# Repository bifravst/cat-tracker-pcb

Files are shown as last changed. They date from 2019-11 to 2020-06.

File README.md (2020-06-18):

# Cat Tracker PCB (PCA10015)

Design files for a custom cat tracker board based on the [nRF9160](https://www.nordicsemi.com/Products/Low-power-cellular-IoT/nRF9160).

See [the PDF slides](./presentation.pdf) for an introduction to the design.

## Front

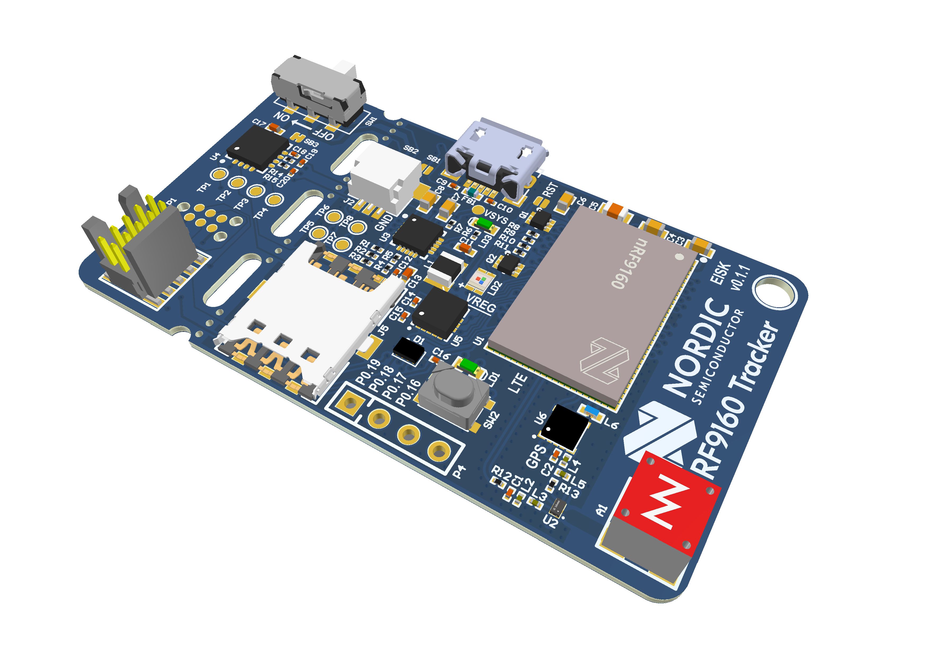
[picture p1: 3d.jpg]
3D Rendering


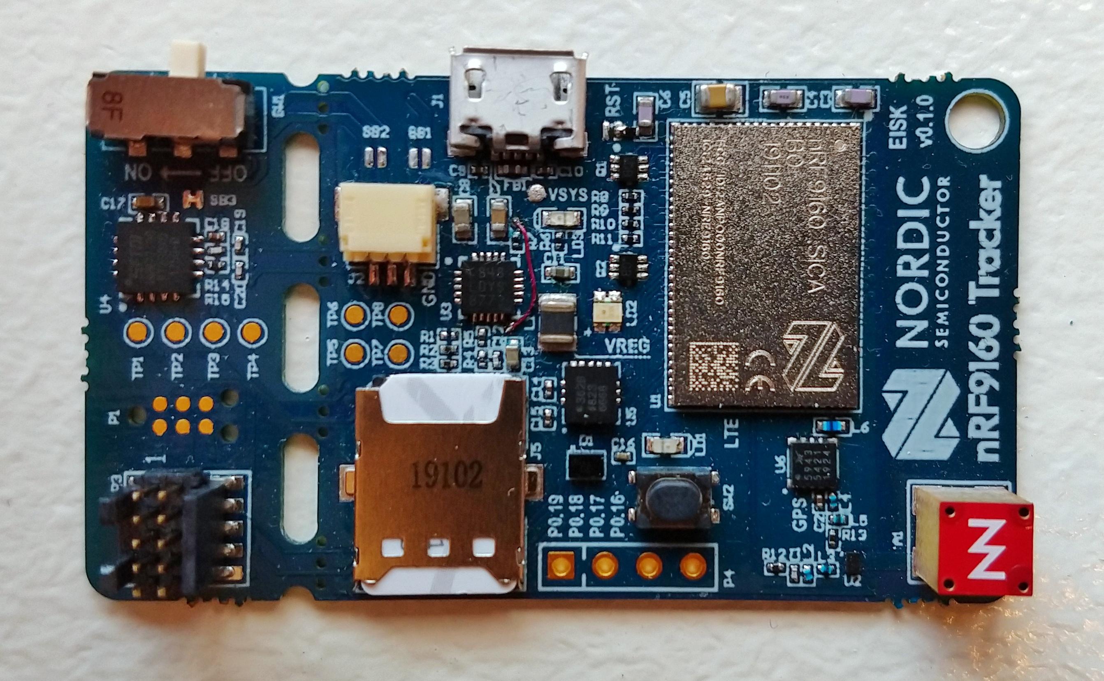
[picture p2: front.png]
Front


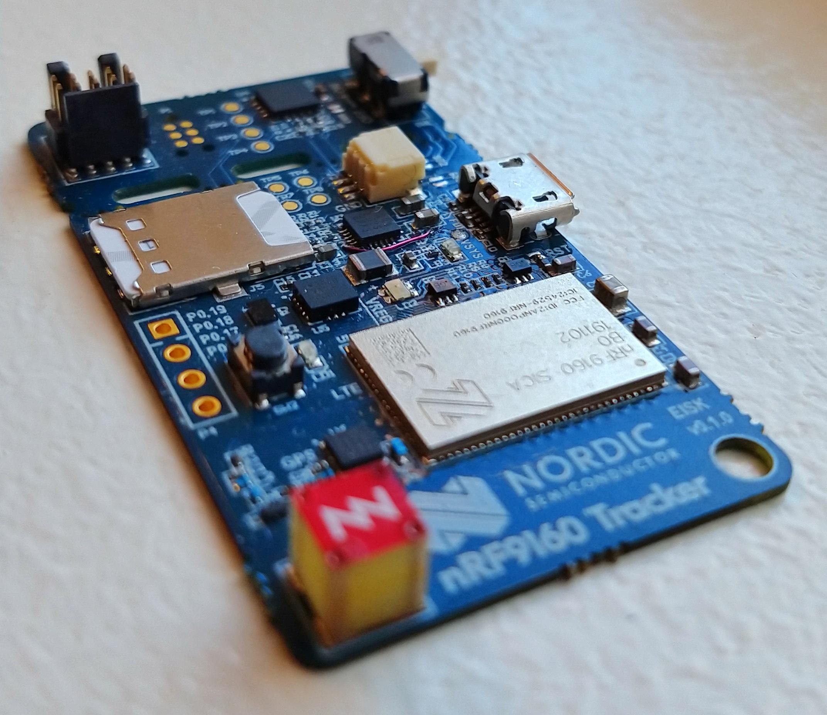
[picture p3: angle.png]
Front (angled view)


## Back

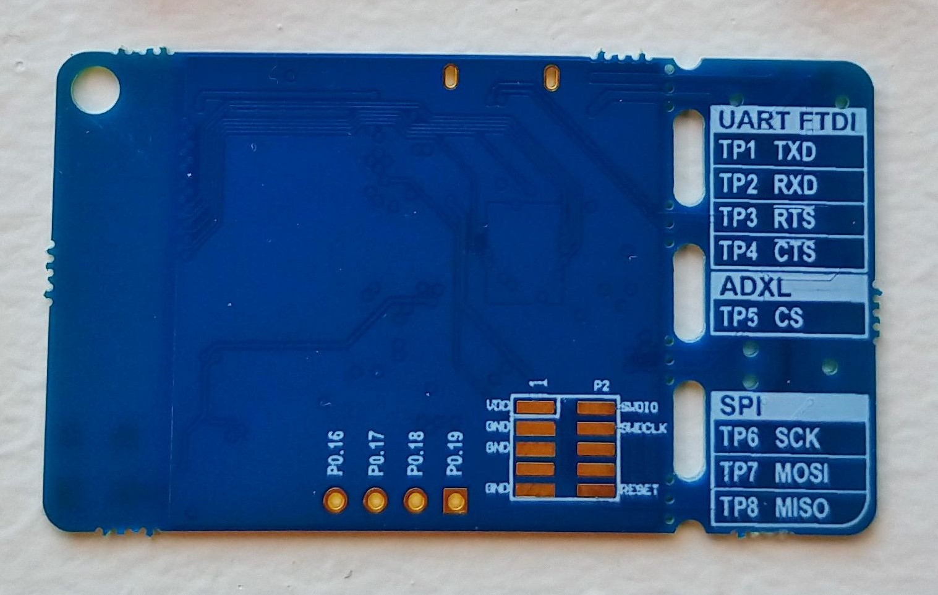
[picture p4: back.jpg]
Back


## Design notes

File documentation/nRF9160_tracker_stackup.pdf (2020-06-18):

nRF9160 Tracker Demo
v0.1.2

## 1 PCB Stackup

## 1.1 Stackup

Type | Material | Height [µm] Dk | Df
Mask | – | 15 | 3.5 | –
Prepreg | FR-4 | 70 | 4.2 | 0.02
Core | FR-4 | 500 | 4.5 | 0.02
Prepreg | FR-4 | 70 | 4.2 | 0.02
Mask | – | 15 | 3.5 | –
Type | Material | Height [µm] Weight [oz]
Finish | HASL-Pb Free 18 | 1/2
Cond | Cu | 18 | 1/2
Cond | Cu | 35 | 1

Top layer
Upper layer pair
Mid layer 1

(Vias are not shown)

Mid layer 2
Lower layer pair
Bottom layer

## 1.2 Layer Stack in Altium Designer 20

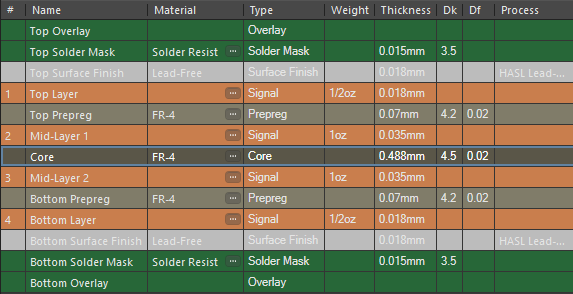
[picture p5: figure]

Figure 1: The Layer Stack of the PCB in Altium Designer 20.

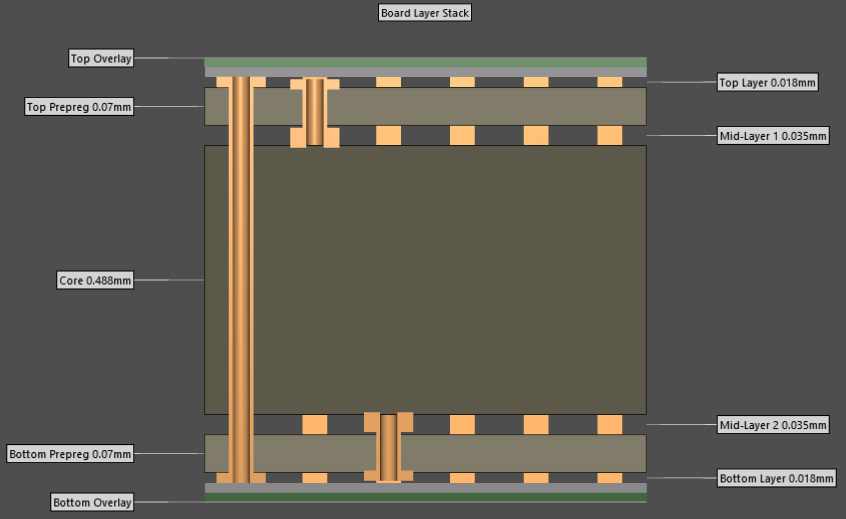
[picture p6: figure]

Figure 2: The Board Layer Stack, with real relative layer heights.

The total PCB thickness is approximately 0.8 mm.

## 1.3 Impedance Calculations

The transmission lines in the RF front end are grounded coplanar waveguides (GCPWs), which require a bottom ground plane in addition to coplanar ground planes. Simulations of the transmission lines are necessary to obtain a characteristic impedance of

Z0 = 50 Ω,

However, this is very challenging when embedding GCPWs on very small PCBs as the nRF9160 Tracker. It is important to have in mind that Z0 is dispersive and depends on the effective permittivity εeff, which satisfies

1 ≤ εeff ≤ εr

Only the upper layer pair is used in the nRF9160 Tracker, thus, the GCPWs for the LTE and the GPS circuitry only depend on the prepreg layer height and not the PCB core.

Altium Designer 20 can compute the characteristic impedance (in the Layer Stack Manager). It incorporates the solder mask layer and optionally, the surface finish layer in its calculation.

Free calculators like AppCAD Design Assistant (https://www.broadcom.com/appcad) or Saturn PCB Toolkit (http://saturnpcb.com/pcb_toolkit/) can also be used to calculate the characteristic line impedance Z0, as well as the effective permittivity εeff. However, values from these calculators do not take surface finish and solder mask into account, unlike Altium Designer 20. A comparison of calculated transmission line values on the nRF9160 Tracker is presented in table 1, when the clearance, the dielectric thickness and the relative permittivity, respectively are:

S = 200 μm,
t = 70 μm,
εr = 4.2.

Table 1: Comparison of calculated transmission line values in Altium and AppCAD.

| | Altium | AppCAD
Impedance | Z0
| [Ω] | 50.0 | 51.0
Delay | Tp
| [ns/m] | 6.08 | 5.46
Line Width | W [μm] | 102 | 150

The AppCAD line width value of W = 150 μm is used in nRF9160 Tracker v0.1.2.

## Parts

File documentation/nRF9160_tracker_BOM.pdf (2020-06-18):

Item # | Designator | Description | Name | Quantity | Manufacturer 1 | Manufacturer Part Number 1 | Footprint | LibRef | Note
1 | A1 | CUBE mXTEND Antenna Booster (GSM, UMTS, LTE) | FR01-S4-250 | 1 | Fractus | FR01-S4-250 | FRACTUS_CUBE_mXTEND | ANT:CUBE_mXTEND
2 | C1 | Capacitor, NP0, ±10%, 10V | 3pF | 1 | Murata | GJM0335C1E3R0WB01D | CAPC0603X03L_C
3 | C2, C9, C14, C15, C18 | Capacitor, X5R, ±10%, 10V | 100nF | 5 | | | CAPC0603X03L_C
4 | C3, C4, C6 | Capacitor, X5R, ±10%, 6.3V | 4.7µF | 3 | | | CAPC1608X06L
5 | C5 | Capacitor, X5R, ±20%, 6.3V | 47µF | 1 | Murata | GRM21BR60J476ME15L | CAPC2012X11L
6 | C7, C8 | Capacitor, X7R, ±10% | 10µF | 2 | | | CAPC1608X06L
7 | C10 | Capacitor, X5R, ±10%, 10V | 10nF | 1 | | | CAPC0603X03L_C
8 | C11 | Capacitor, X5R, ±10%, 16V | 2.2µF | 1 | | | CAPC1005X04L
9 | C12 | Capacitor, NP0 | 10pF | 1 | | | CAPC0603X03L_C
10 | C13 | Capacitor, X5R, ±20% | 10µF | 1 | | | CAPC1005X04L
11 | C16 | Capacitor, X5R, ±10%, 10V | 1µF | 1 | | | CAPC0603X03L_C
12 | C17 | Capacitor, X5R, ±10%, 16V | 4.7µF | 1 | Murata | GRM155R60J475ME47D | CAPC1005X04L
13 | C19, C20 | Capacitor, NP0 | 47pF | 2 | Murata | GRM0335C1E470JA01D | CAPC0603X03L_C
14 | D1 | EMI Network Filter Arrays SIM CARD EMI FILTER WITH ESD PROTECTION | CM1402 | 1 | ON Semiconductor | CM1402-03CP | CM1402
15 | FB1 | Ferrite Bead, 120 Ohm @ 100MHz, 500mA, 250 mOhm Max | 120R/550mA | 1 | Murata | BLM15AG121SN1D | INDC1005X04L
16 | J1 | MicroUSB-B-SMT | USB Micro B | 1 | Amphenol ICC / FCI | 10118193-0001LF | USB-Micro-B-RA-SMD-PiP
17 | J2 | 1.0mm pitch connector side entry SMD | HDR-3, 1mm | 1 | JST | SM03B-SRSS-TB(LF)(SN) | SM03B-SRSS-TB
18 | J5 | Nano SIM Card Connector, Push-Pull Type, 6 Pin, SMT, Profile 1.35mm | SIM8055-6-1-14-00-A_revA1 | 1 | | | GCT_SIM8055-6-1-14-00-A_revA1 | SIM8055-6-1-14-00-A_revA1
19 | L1 | Switching regulator chip inductor, 2-Leads, Body 2.5x2.0x1.1 mm | 10µH | 1 | Wurth Electronics | 74479787247 | IND1008
20 | L2 | Inductor, 350mA, ±3% | 2nH | 1 | Murata | LQW03AW2N0C00D | INDC0603X03L_C
21 | L3 | Inductor, 350mA, ±3% | 8.7nH | 1 | Murata | LQW03AW2N8C00D | INDC0603X03L_C
22 | L4 | Inductor, 350mA, ±3% | 2.8nH | 1 | Murata | LQW03AW2N8C00D | INDC0603X03L_C
23 | L5 | Inductor, 350mA, ±3% | 11nH | 1 | Murata | LQW03AW12NJ00D | INDC0603X03L_C
24 | L6 | Inductor, 600mA, ±0.1nH, 120mΩ, Q=25 | 5.1nH | 1 | Murata | LQW15AN5N1B00D | INDC1005X04L_WW
25 | LD1, LD3 | LED, Green, 0603, 570nm, Vf=1.7V, 2.24..5.6mcd, - 40 to +100°C | L0603G | 2 | Osram Opto | LGL29K-G2J1-24-Z | LED_0603_G | D:LED
26 | LD2 | RGB LED 1.60 mm x 1.60 mm SMD | LED RGB | 1 | | | LED_RGB_0606
27 | Q1, Q2 | MOSFET 2N-CH 30V 0.2A SOT666 | NX3020NAKV | 2 | Nexperia | NX3020NAKV,115 | NX3020NAKV
28 | R1, R2, R3, R12, R13 | | 0R | 5 | | | RESC0603X03L_C | RES:0201
29 | R4 | | 1.5M | 1 | | | RESC0603X03L_C | RES:0201
30 | R5 | | 1.2M | 1 | Panasonic | ERJ-1GEJ125C | RESC0603X03L_C | RES:0201
31 | R6, R7, R11 | | 1k | 3 | | | RESC0603X03L_C | RES:0201
32 | R8 | | 170R | 1 | | | RESC0603X03L_C | RES:0201
33 | R9, R10 | | 143R | 2 | Yageo | RC0201FR-07143RL | RESC0603X03L_C | RES:0201
34 | R14, R15 | | 23R | 2 | Panasonic | ERJ-1GNF23R7C | RESC0603X03L_C | RES:0201
35 | SW1 | SMD slide Switch (ON-ON) | Switch | 1 | Nidec Copal | CL-SB-22A-11T | Switch-Slide-RA-J-Lead-DPDT-8.5x3.5mm
36 | SW2 | SWITCH TACTILE SPST-NO 0.05A 16V | PTS810 | 1 | ITT C&K | PTS810SJM250SMTRLFS | BTN_PTS810 | BUTTON
37 | U1 | Low power System-in-Package with integrated LTE-M/NB-IoT modem and GPS | nRF9160-SICA | 1 | Nordic Semiconductor | NRF9160-SICA-R | LGA50P1600X1050X104-161N
38 | U2 | Wideband RF SPDT Switch | BGS12SN6 | 1 | Infineon | BGS12SN6E6327 | PG-TSNP-6-2
39 | U3 | IC USB POWER MANAGER 20UTQFN | LTC3554 | 1 | Analog Devices / Linear Technology | LTC3554EUD#PBF | QFN40P300X300X80_HS-21N | LTC3554EUD-3#PBF
40 | U4 | USB Bridge, USB to UART USB 2.0 UART Interface 16-QFN (4x4) | FT230XQ | 1 | FTDI | FT230XQ-R | QFN65P400X400X80_HS-17N
41 | U5 | Micropower, 3-Axis, ±2 g/±4 g/±8 g Digital Output MEMS Accelerometer | ADXL362 | 1 | Analog Devices | ADXL362BCCZ-RL7 | LGA50P322X300X114-16N
42 | U6 | GNSS Low-Noise Amplifier Front-End Module with Integrated Pre-Filter and Post-Filter | SKY65943-11 | 1 | Skyworks Solutions | SKY65943-11 | SKY6594311

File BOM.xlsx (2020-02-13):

Quantity | Designator | Name | Footprint Doc | Description | Supplier Packaging 1 | Manufacturer 1 | Manufacturer Part Number 1 | Supplier 1 | Supplier Part Number 1
1 | A1 | FR01-S4-250 |  | CUBE mXTEND Antenna Booster (GSM, UMTS, LTE) | Cut Tape | Fractus | FR01-S4-250 | Digi-Key | 2115-FR01-S4-250CT-ND
1 | C1 | 3pF | 0201 | Capacitor, NP0, ±0.05pF, 25V | Tape & Reel | Murata | GJM0335C1E3R0WB01D | Mouser | 81-GJM0335C1E3R0WB1D
5 | C2, C9, C14, C15, C18 | 100nF | 0201 | Capacitor, X5R, ±10%, 10V
3 | C3, C4, C6 | 4.7µF | 0603 | Capacitor, X5R, ±10%, 6.3V
1 | C5 | 47µF | 0805 | Capacitor, X5R, ±20%, 6.3V
2 | C7, C8 | 10µF | 0603 | Capacitor, X7R, ±10%
1 | C10 | 10nF | 0201 | Capacitor, X5R, ±10%, 10V
1 | C11 | 2.2µF | 0402 | Capacitor, X5R, ±10%, 16V
1 | C12 | 10pF | 0201 | Capacitor, NP0
1 | C13 | 10µF | 0402 | Capacitor, X5R, ±20%
1 | C16 | 1µF | 0201 | Capacitor, X5R, ±10%, 10V
1 | C17 | 4.7µF | 0402 | Capacitor, X5R, ±10%, 16V | Cut Tape | Murata | GRM155R60J475ME47D | Digi-Key | 490-5915-1-ND
2 | C19, C20 | 47pF | 0201 | Capacitor, NP0 | Cut Tape | Murata | GRM0335C1E470JA01D | Digi-Key | 490-1256-1-ND
1 | D1 | CM1402 |  | EMI Network Filter Arrays SIM CARD EMI FILTER WITH ESD PROTECTION | Cut Tape | ON Semiconductor | CM1402-03CP | Digi-Key | CM1402-03CPOSCT-ND
1 | FB1 | 120R/550mA | 0402 | Ferrite Bead, 120 Ohm @ 100MHz, 500mA, 250 mOhm Max | Cut Tape | Murata | BLM15AG121SN1D | Digi-Key | 490-1005-1-ND
1 | J1 | MicroUSB-B |  | MicroUSB-B-SMT |  | AMPHENOL ICC (FCI) | 10118193-0001LF | Mouser | 649-10118193-0001LF
1 | J2 | HDR-3, 1mm |  | 1.0mm pitch connector side entry SMD | Cut Tape | JST | SM03B-SRSS-TB(LF)(SN) | Digi-Key | 455-1803-1-ND
1 | J5 | SIM8055-6-1-14-00-A_revA1 |  | Nano SIM Card Connector, Push-Pull Type, 6 Pin, SMT, Profile 1.35mm | Cut Tape | GCT | SIM8055-6-1-14-00-A | Digi-Key | ‎2073-SIM8055-6-1-14-00-ACT-ND‎
1 | L1 | 10µH | 1008 | Switching regulator chip inductor, 2-Leads, Body 2.5x2.0x1.1 mm | Cut Tape | Wurth Electronics | 74479787247 | Digi-Key | 732-14079-1-ND
1 | L2 | 2nH | 0201 | Inductor, 490mA, 100mOhm | Cut Tape | Murata | LQW03AW2N0C00D | Digi-Key | 490-13822-1-ND
1 | L3 | 8.7nH | 0201 | Inductor, 290mA, 420mOhm | Cut Tape | Murata | LQW03AW2N8C00D | Digi-Key | 490-13826-1-ND
1 | L4 | 2.8nH | 0201 | Inductor, 600mA, 80mOhm | Cut Tape | Murata | LQW03AW2N8C00D | Digi-Key | 490-13826-1-ND
1 | L5 | 11nH | 0201 | Inductor, 280mA, 540mOhm | Cut Tape | Murata | LQW03AW12NJ00D | Digi-Key | 490-13814-1-ND
1 | L6 | 5.1nH | 0402 | Inductor, 600mA, ±0.1nH, 120mΩ, Q=25 | Cut Tape | Murata | LQW15AN5N1B00D | Digi-Key | 490-6831-1-ND
2 | LD1, LD3 | L0603G | 0603 | LED, Green, 0603, 570nm, Vf=1.7V, 2.24..5.6mcd, - 40 to +100°C | Cut Tape | Osram Opto | LGL29K-G2J1-24-Z | Digi-Key | 475-2709-1-ND
1 | LD2 | LED RGB | 0606 | RGB LED 1.60 mm x 1.60 mm SMD | Cut Tape | Lite-On Inc. | LTST-C19HE1WT | Digi-Key | 160-2162-1-ND
2 | Q1, Q2 | NX3020NAKV | SOT666 | MOSFET 2N-CH 30V 0.2A SOT666 | Cut Tape | Nexperia | NX3020NAKV,115 | Digi-Key | 1727-1287-1-ND
5 | R1, R2, R3, R12, R13 | 0R | 0201
1 | R4 | 1.5M | 0201
1 | R5 | 1.2M | 0201
3 | R6, R7, R11 | 1k | 0201
1 | R8 | 170R | 0201
2 | R9, R10 | 143R | 0201
2 | R14, R15 | 23R | 0201
1 | SW1 | Switch |  | SMD slide Switch (ON-ON) | Cut Tape | Nidec Copal | CL-SB-22A-11T | Digi-Key | 563-1340-1-ND
1 | SW2 | PTS810 |  | SWITCH TACTILE SPST-NO 0.05A 16V | Cut Tape | ITT C&K | PTS810SJM250SMTRLFS | Digi-Key | CKN10502CT-ND
1 | U1 | nRF9160-SICA | LGA-161 | Low power System-in-Package with integrated LTE-M/NB-IoT modem and GPS | Cut Tape | Nordic Semiconductor | NRF9160-SICA-R7 | Digi-Key | 1490-1076-1-ND
1 | U2 | BGS12SN6 | TSNP-6-2 | Wideband RF SPDT Switch | Cut Tape | Infineon | BGS12SN6E6327XTSA1 | Digi-Key | BGS12SN6E6327XTSA1CT-ND
1 | U3 | LTC3554 |  | IC USB POWER MANAGER 20UTQFN | Tube | Analog Devices / Linear Technology | LTC3554EUD#PBF | Digi-Key | LTC3554EUD#PBF-ND
1 | U4 | FT230XQ | QFN-16 | USB Bridge, USB to UART USB 2.0 UART Interface 16-QFN (4x4) | Cut Tape | FTDI | FT230XQ-R | Digi-Key | 768-1130-1-ND
1 | U5 | ADXL362 | LGA-16 | Micropower, 3-Axis, ±2 g/±4 g/±8 g Digital Output MEMS Accelerometer | Cut Tape | Analog Devices | ADXL362BCCZ-RL7 | Digi-Key | ADXL362BCCZ-RL7CT-ND
1 | U6 | SKY65943-11 | MCM-10 | GNSS LNA Front-End Module with Integrated Pre-Filter and Post-Filter | Cut Tape | Skyworks Solutions | SKY65943-11 | Digi-Key | 863-2032-1-ND
 |  | RF components (high Q)
 |  | Generic

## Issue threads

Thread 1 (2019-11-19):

Add schematics

coderbyheart, 2019-11-19:

martinjuhasz, 2020-02-11:
Hey! Will there be a BOM and/or Gerber files available for this PCB at some point?
This looks like a stripped down Thingy with just the necessary parts for device tracking?
Would love to be able to build one myself!

coderbyheart, 2020-02-11:
Hei Martin! Thanks for reaching out, I have passed on your request for the BOM, it will definitely be included with the schematics, but right now I have no ETA when they will be ready.

Closed 2020-02-13.

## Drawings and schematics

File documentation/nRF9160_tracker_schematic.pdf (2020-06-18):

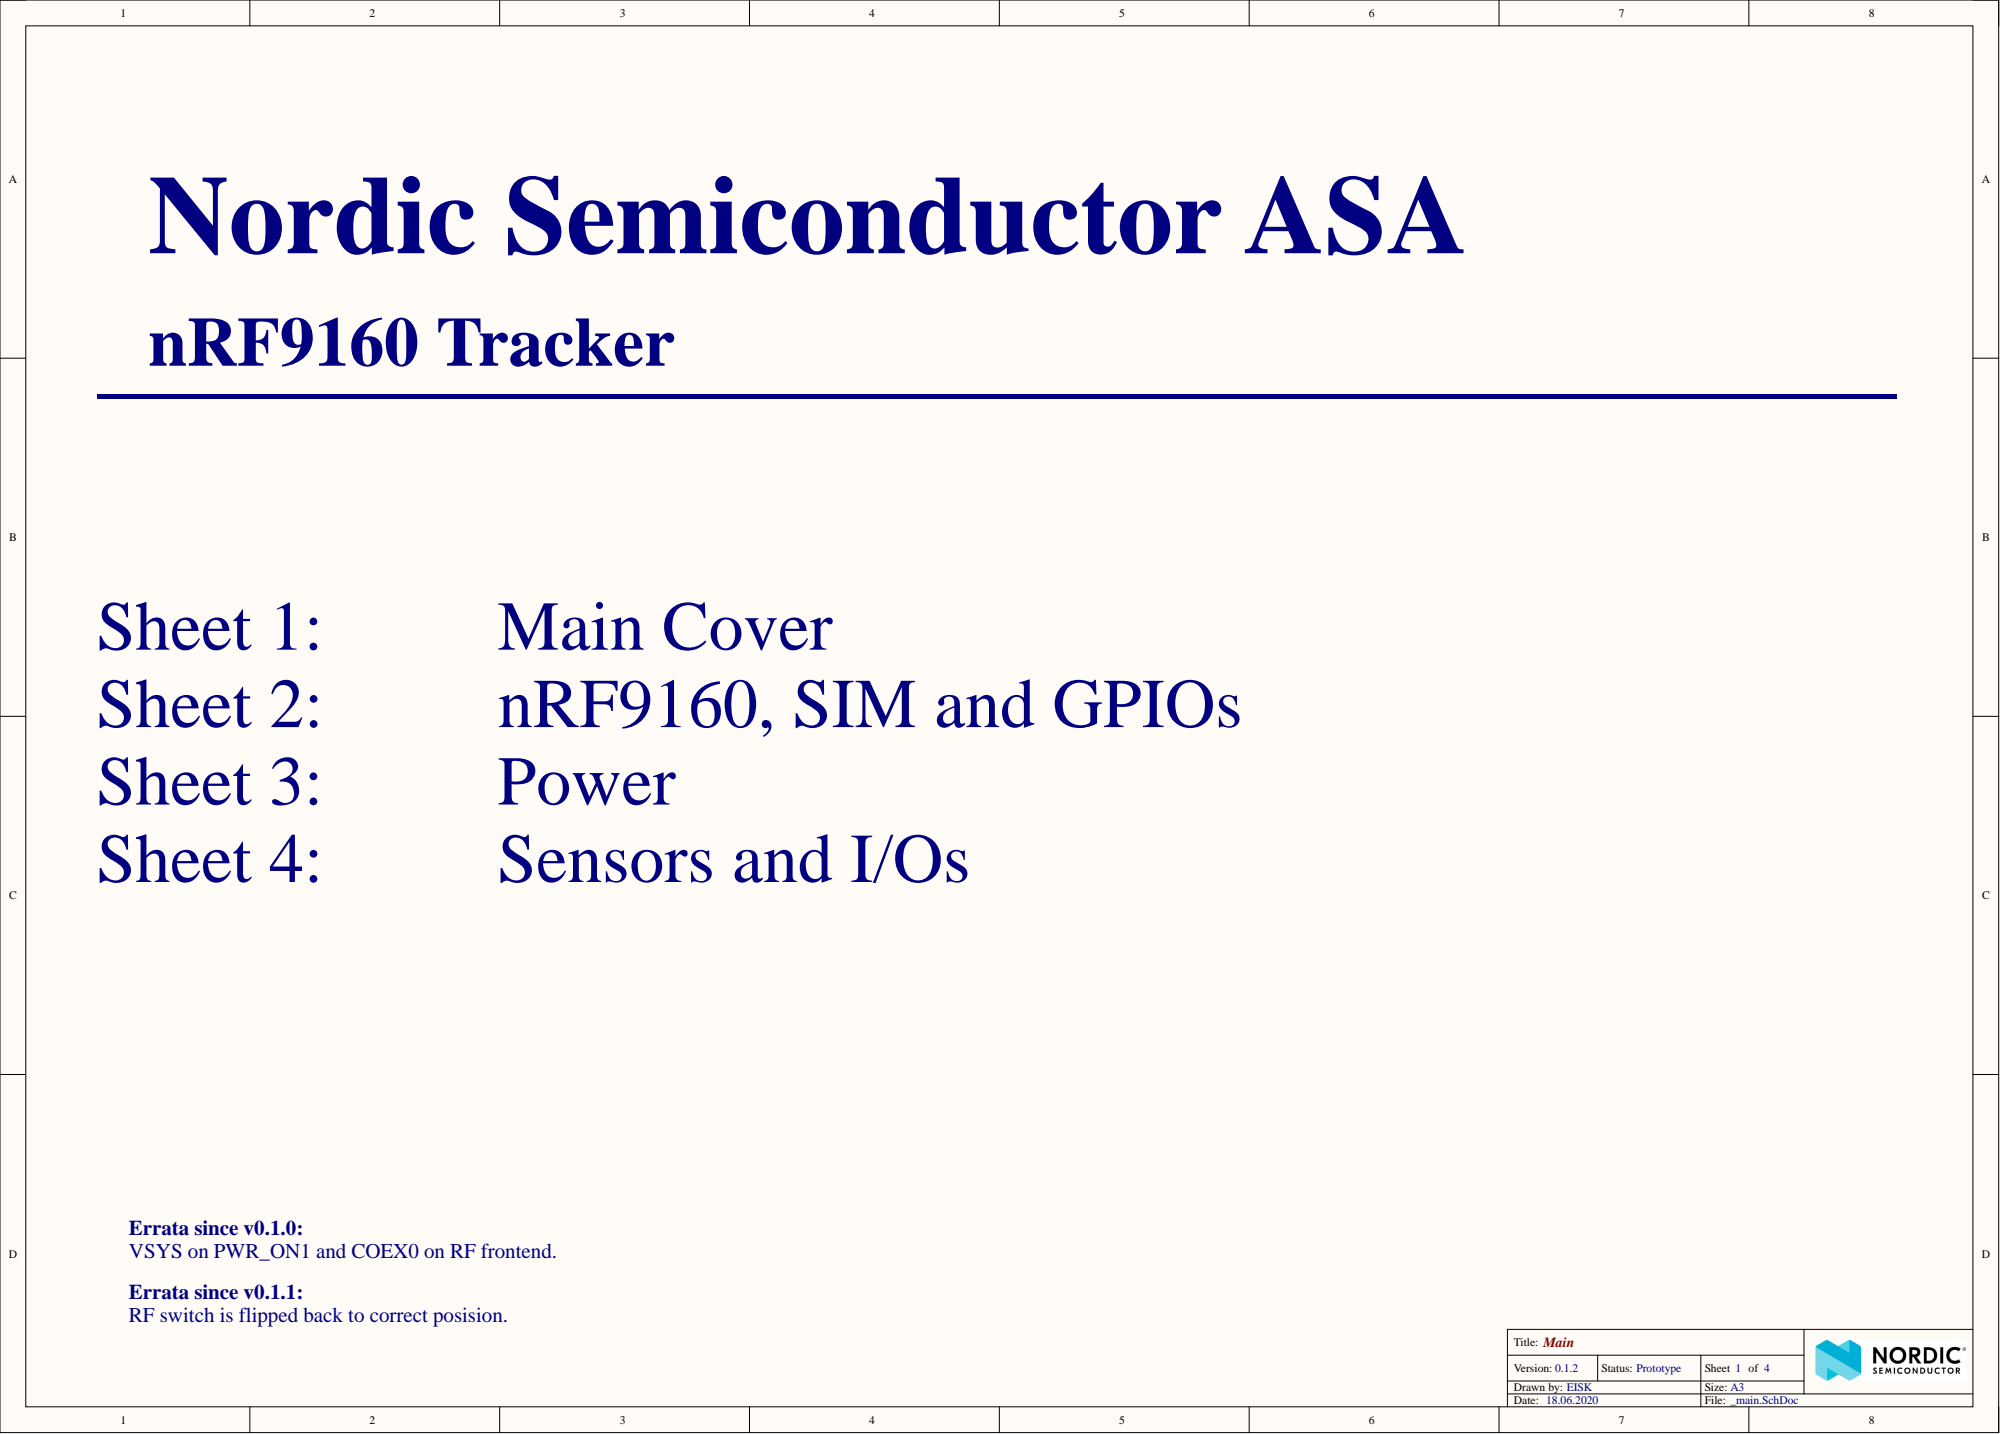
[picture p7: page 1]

Errata since v0.1.0:
VSYS on PWR_ON1 and COEX0 on RF frontend.

Errata since v0.1.1:
RF switch is flipped back to correct posision.

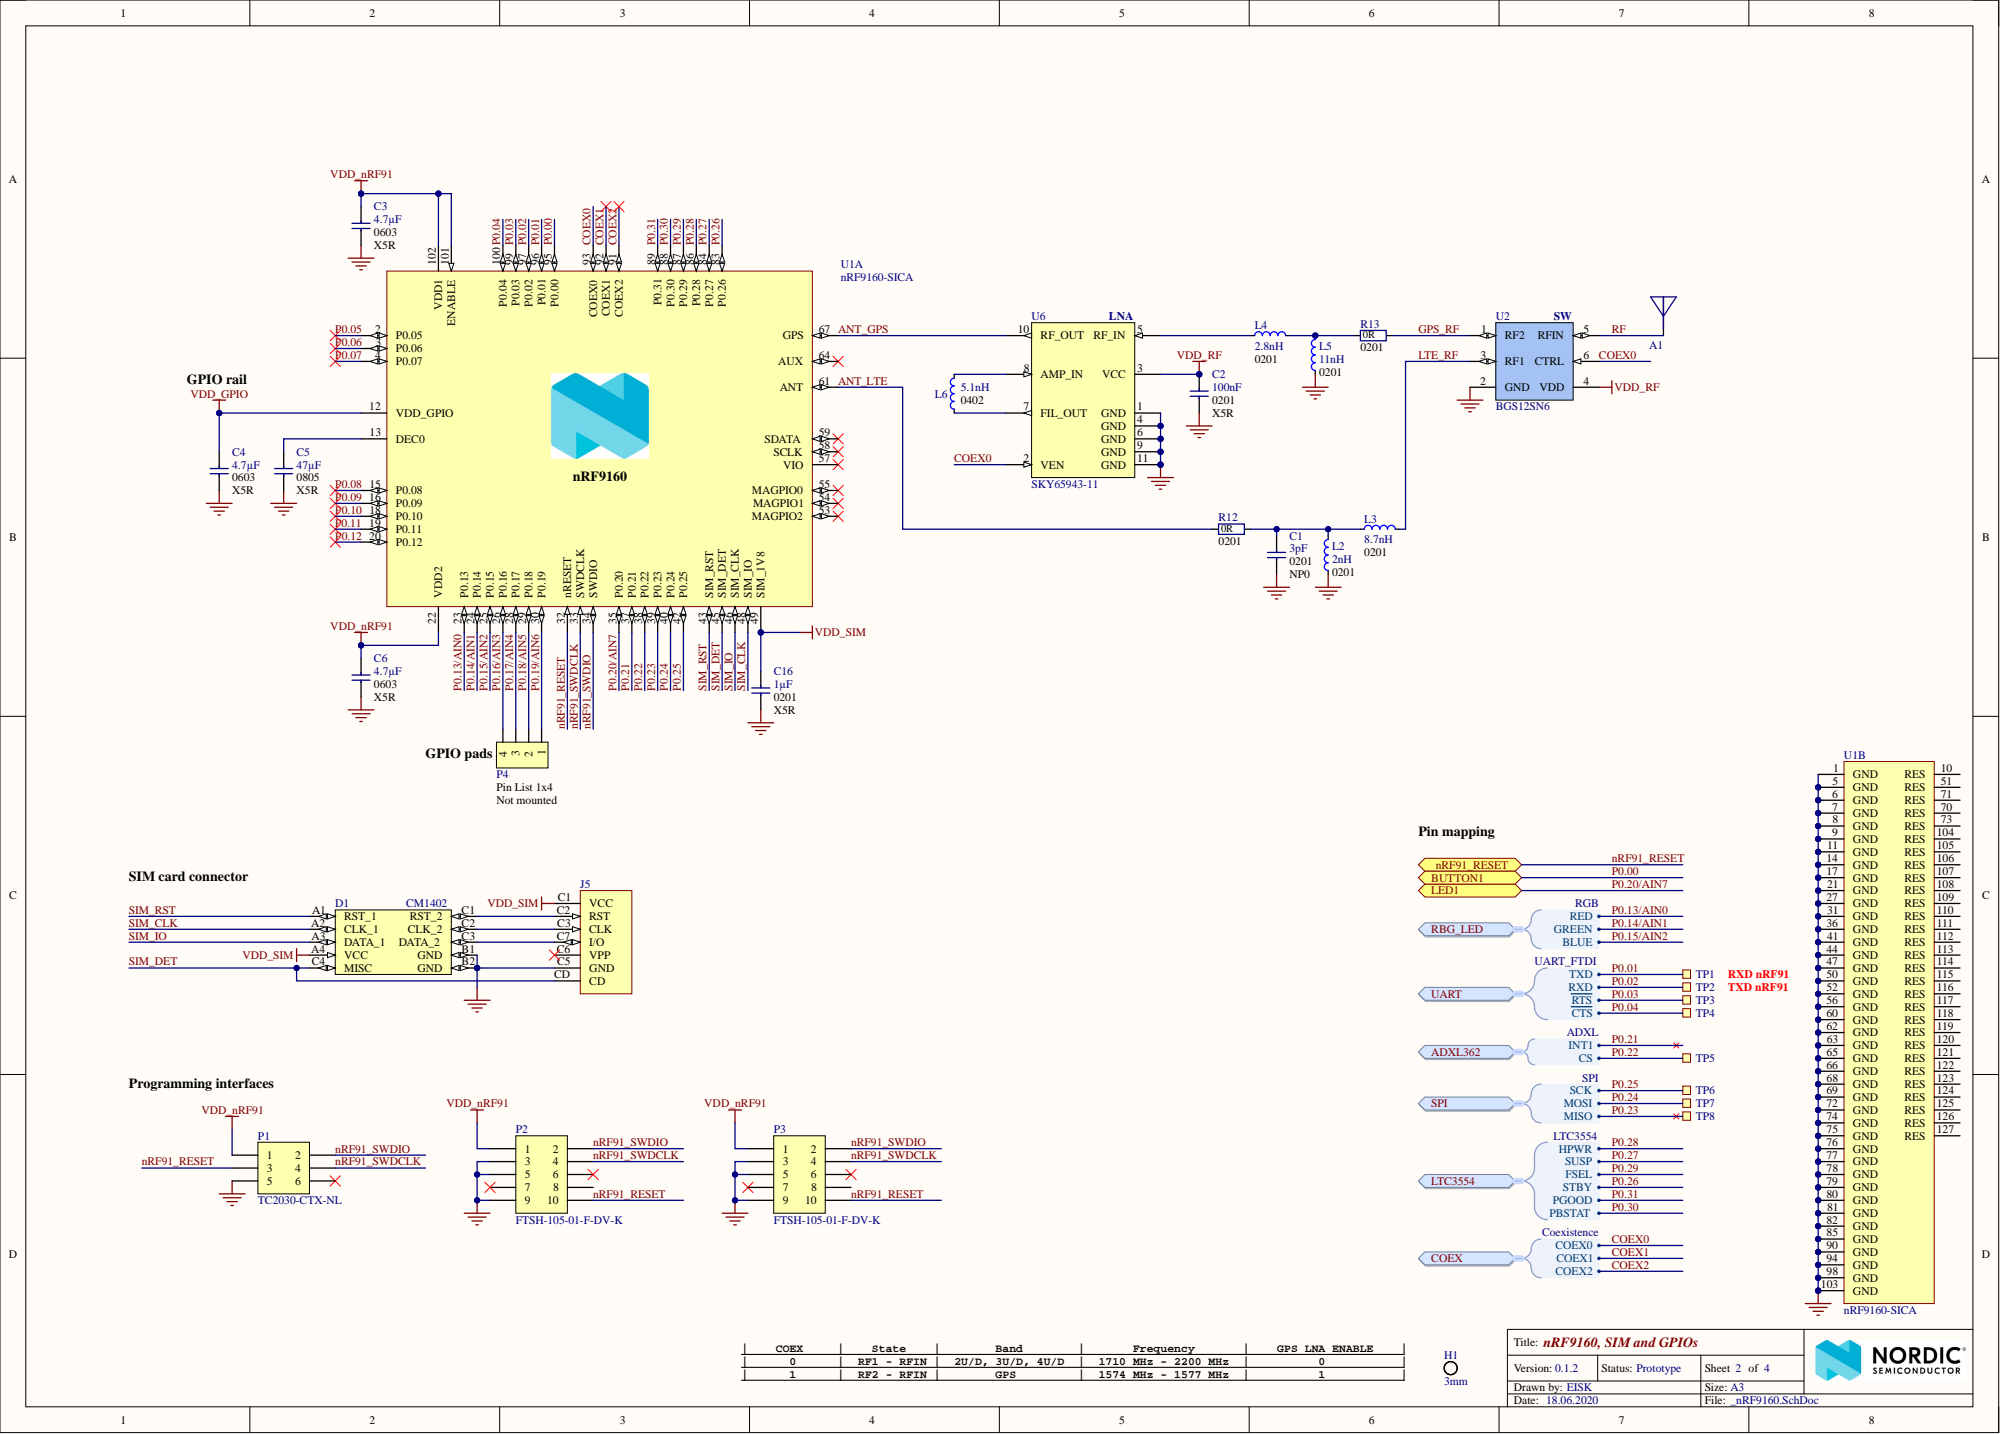
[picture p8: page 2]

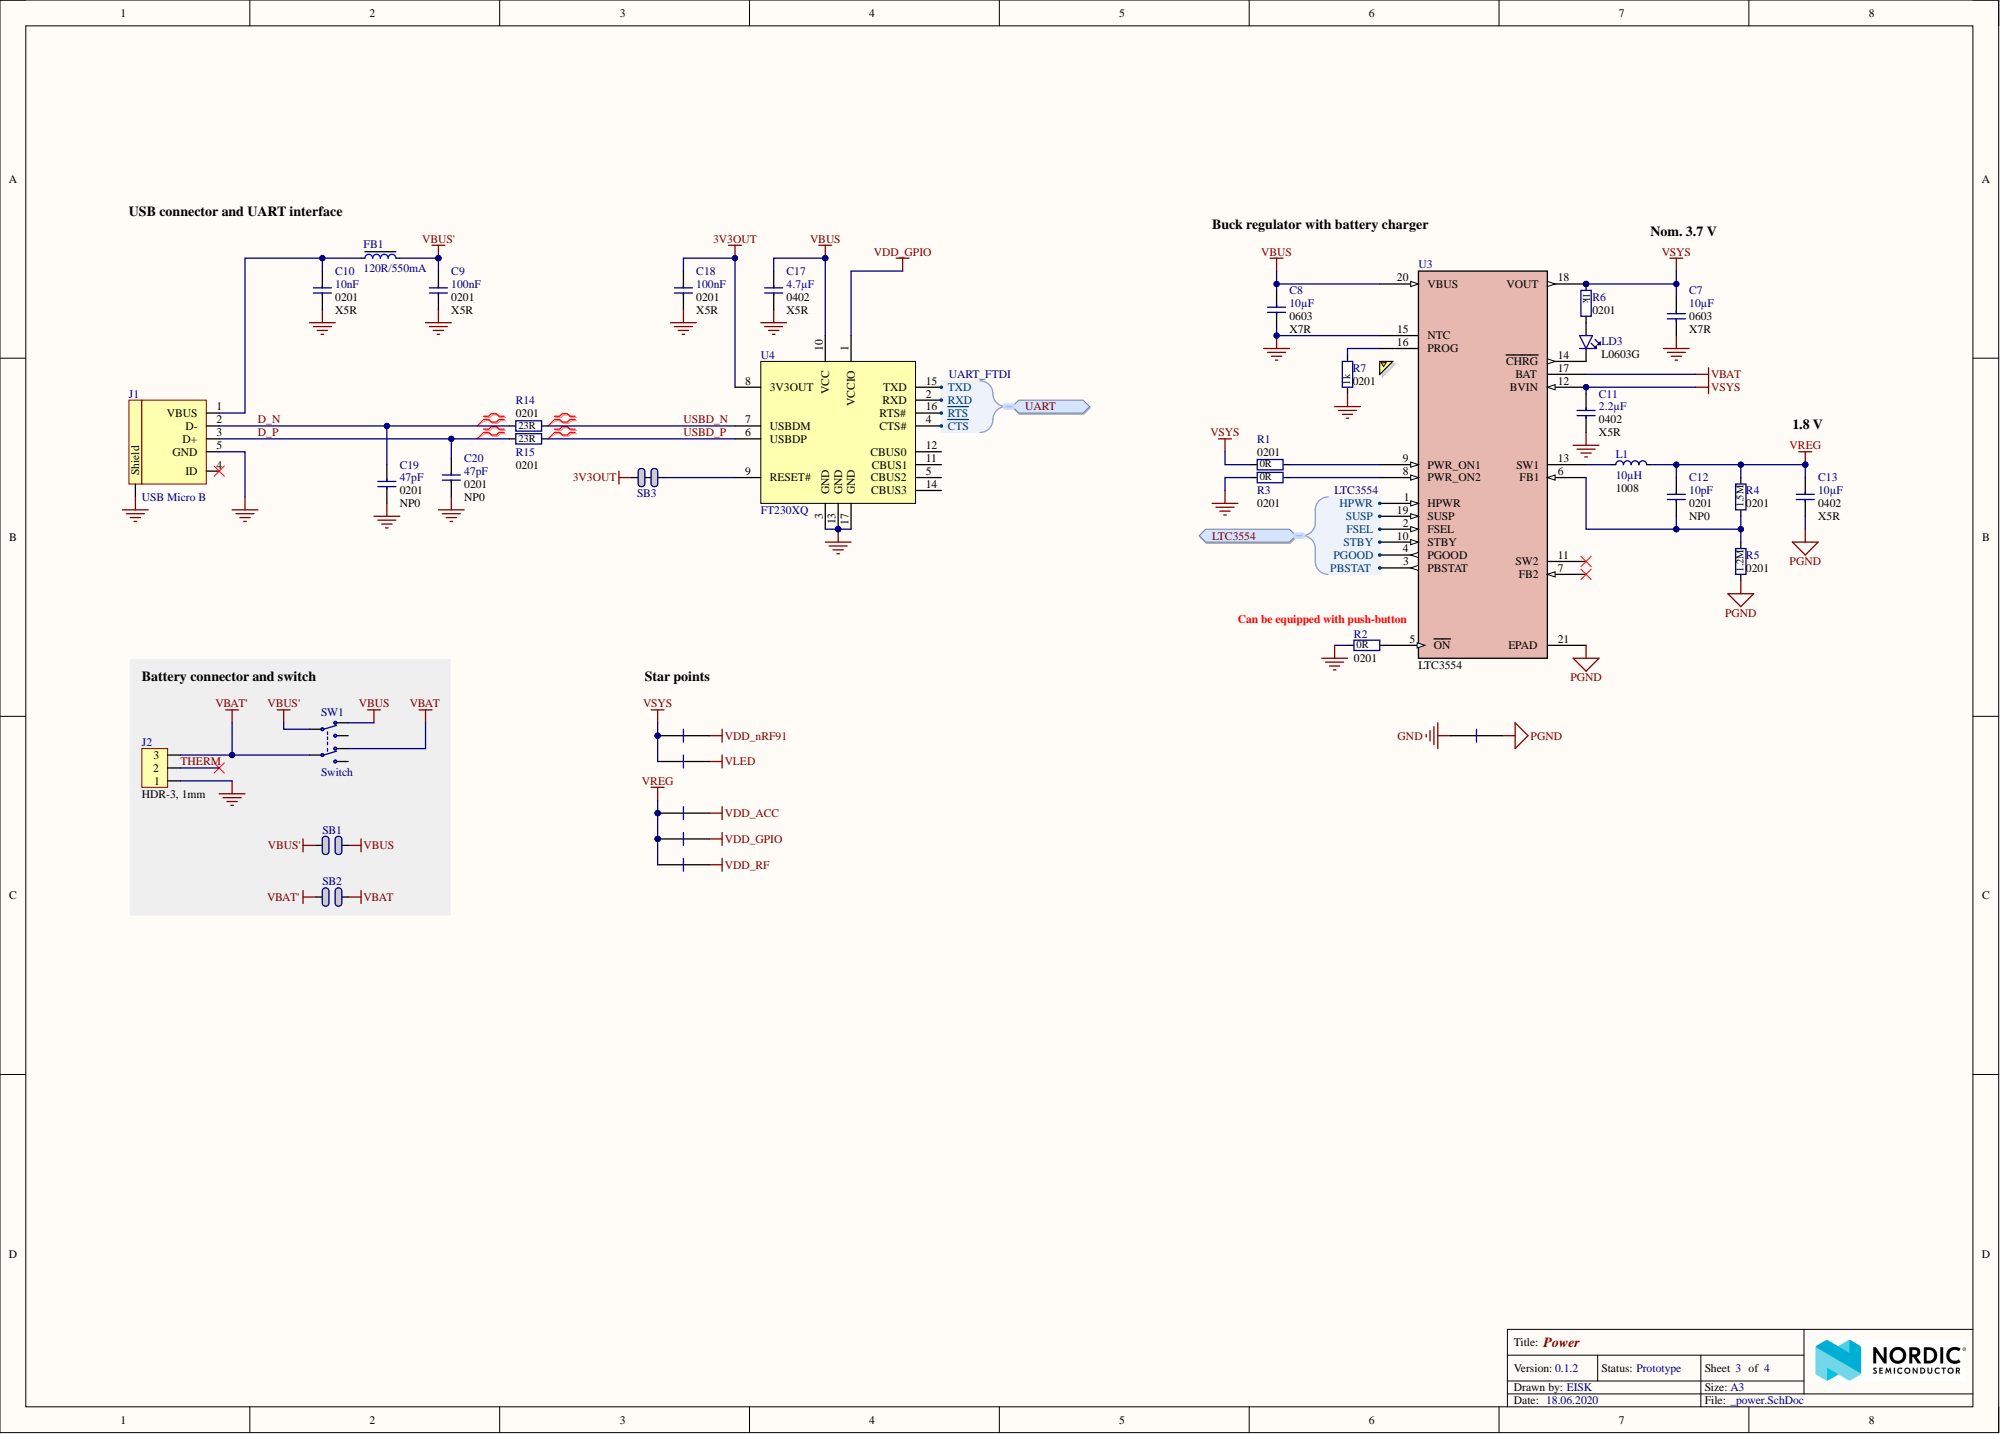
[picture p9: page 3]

USB connector and UAR

Battery connector and switch

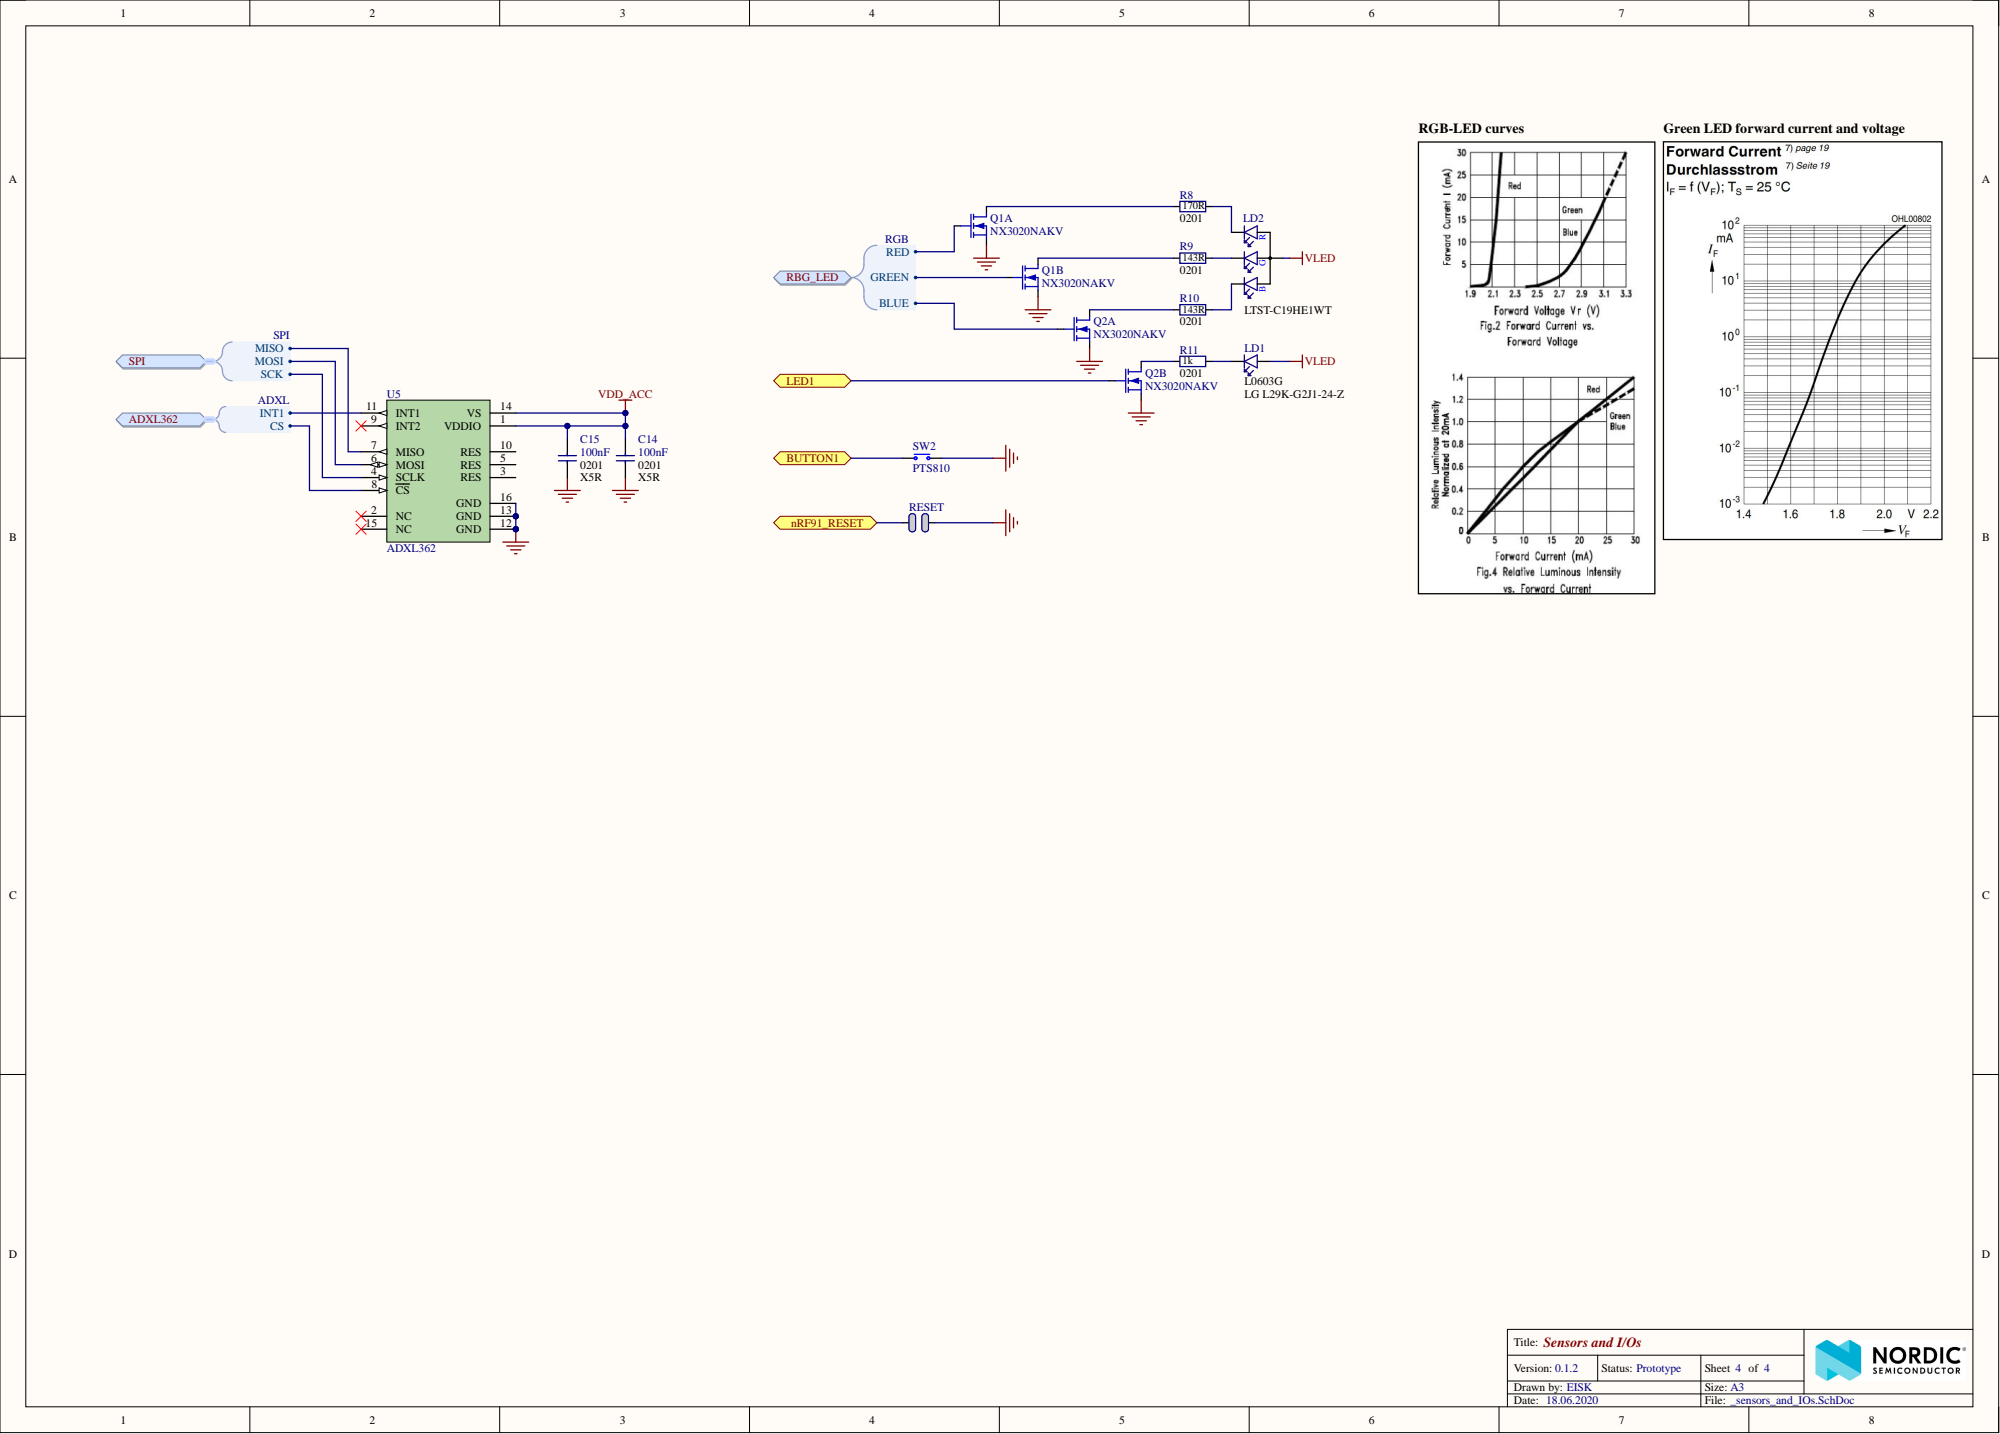
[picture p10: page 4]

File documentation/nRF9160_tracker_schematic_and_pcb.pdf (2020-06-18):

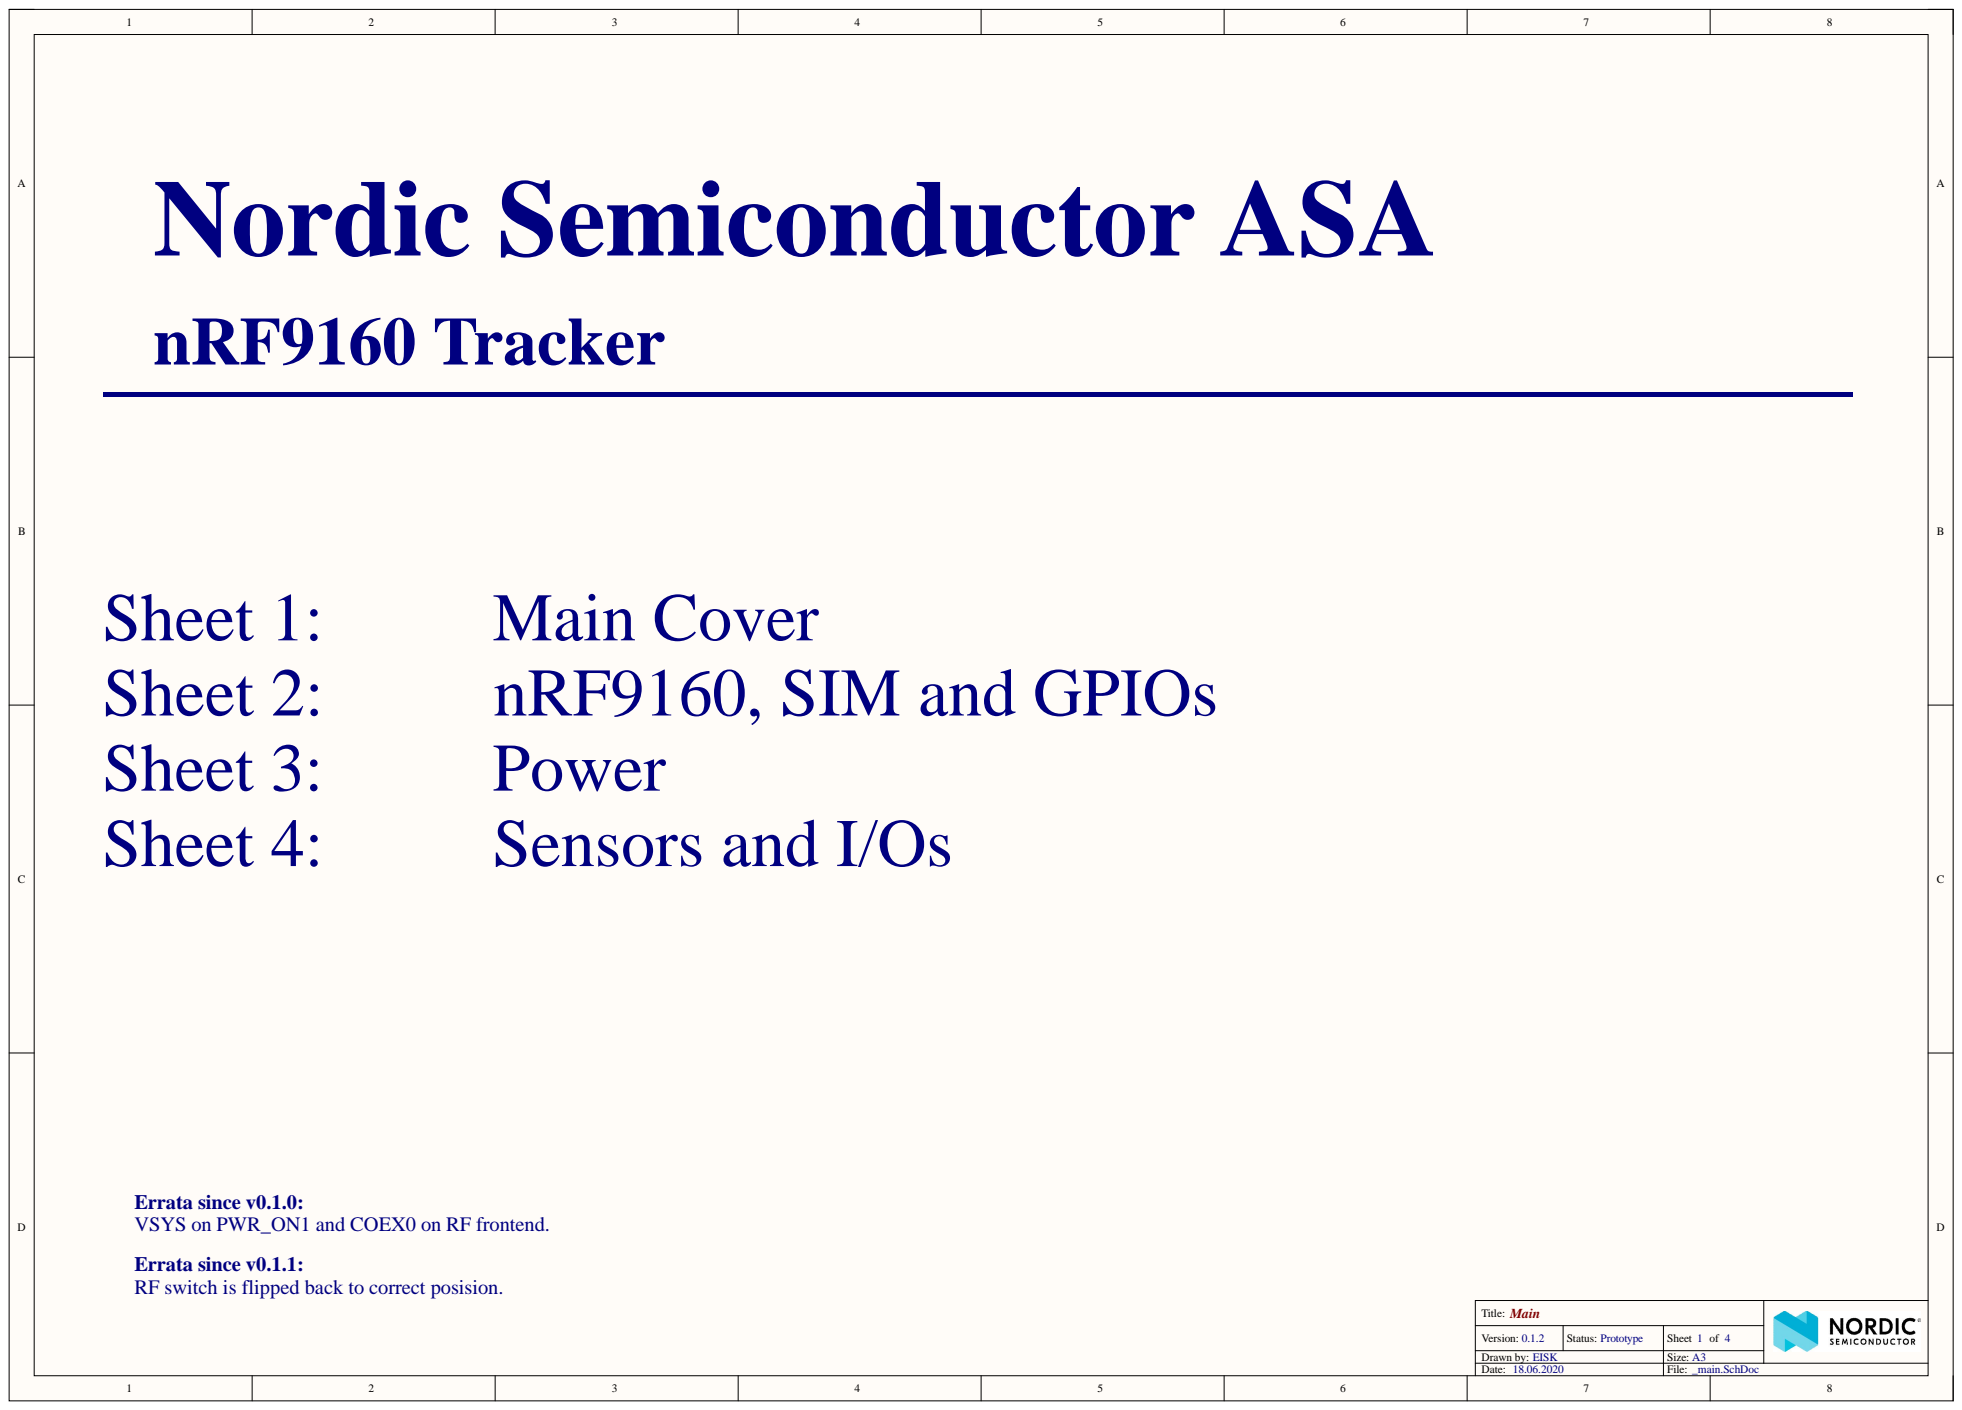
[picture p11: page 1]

Errata since v0.1.0:
VSYS on PWR_ON1 and COEX0 on RF frontend.

Errata since v0.1.1:
RF switch is flipped back to correct posision.

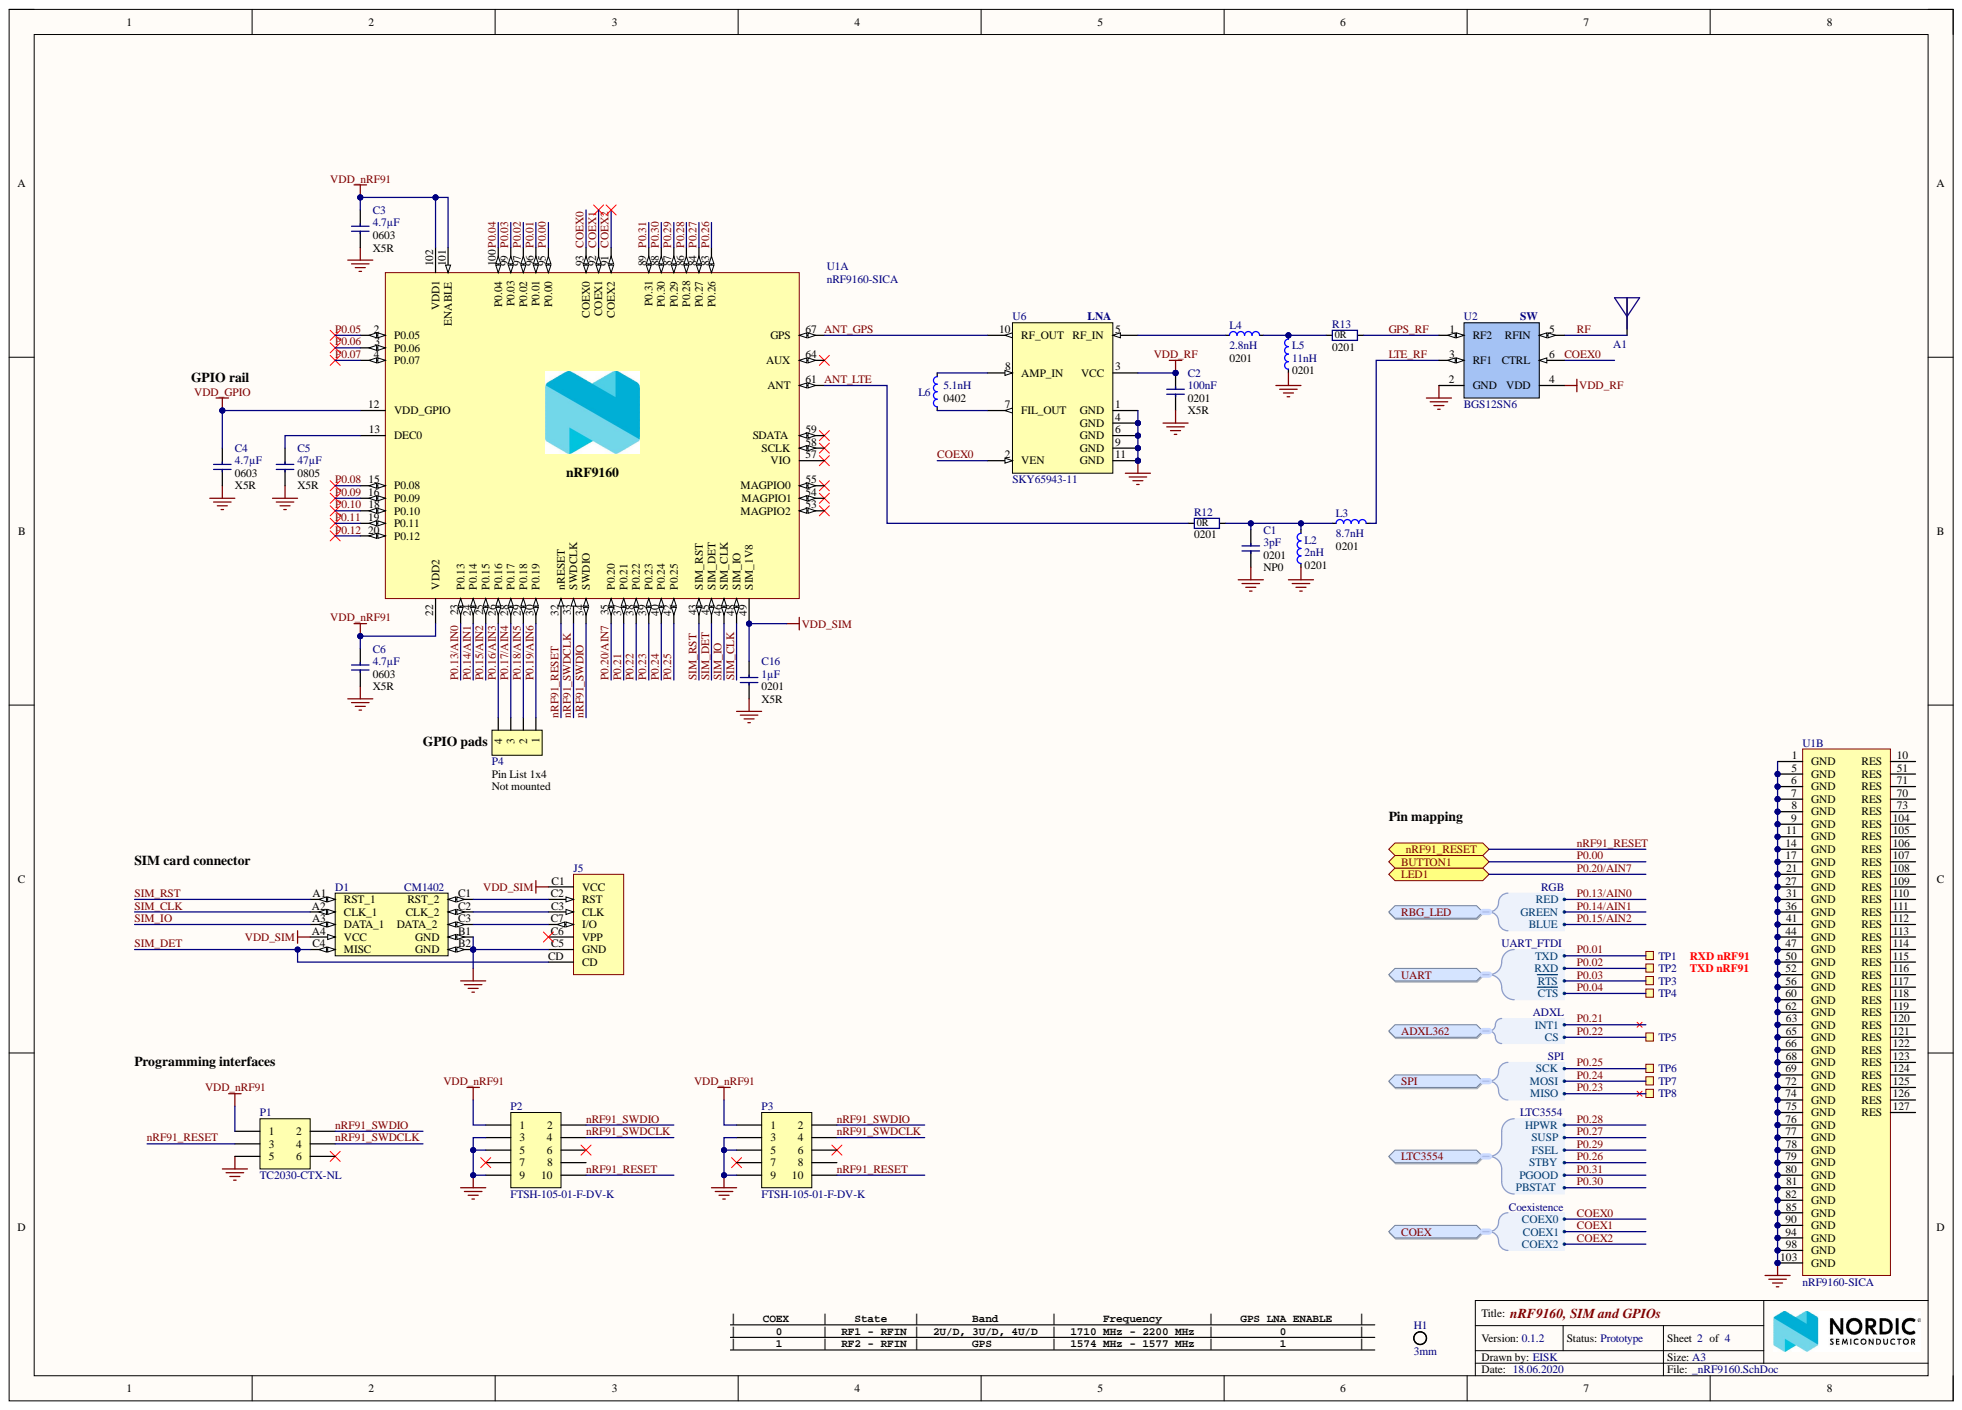
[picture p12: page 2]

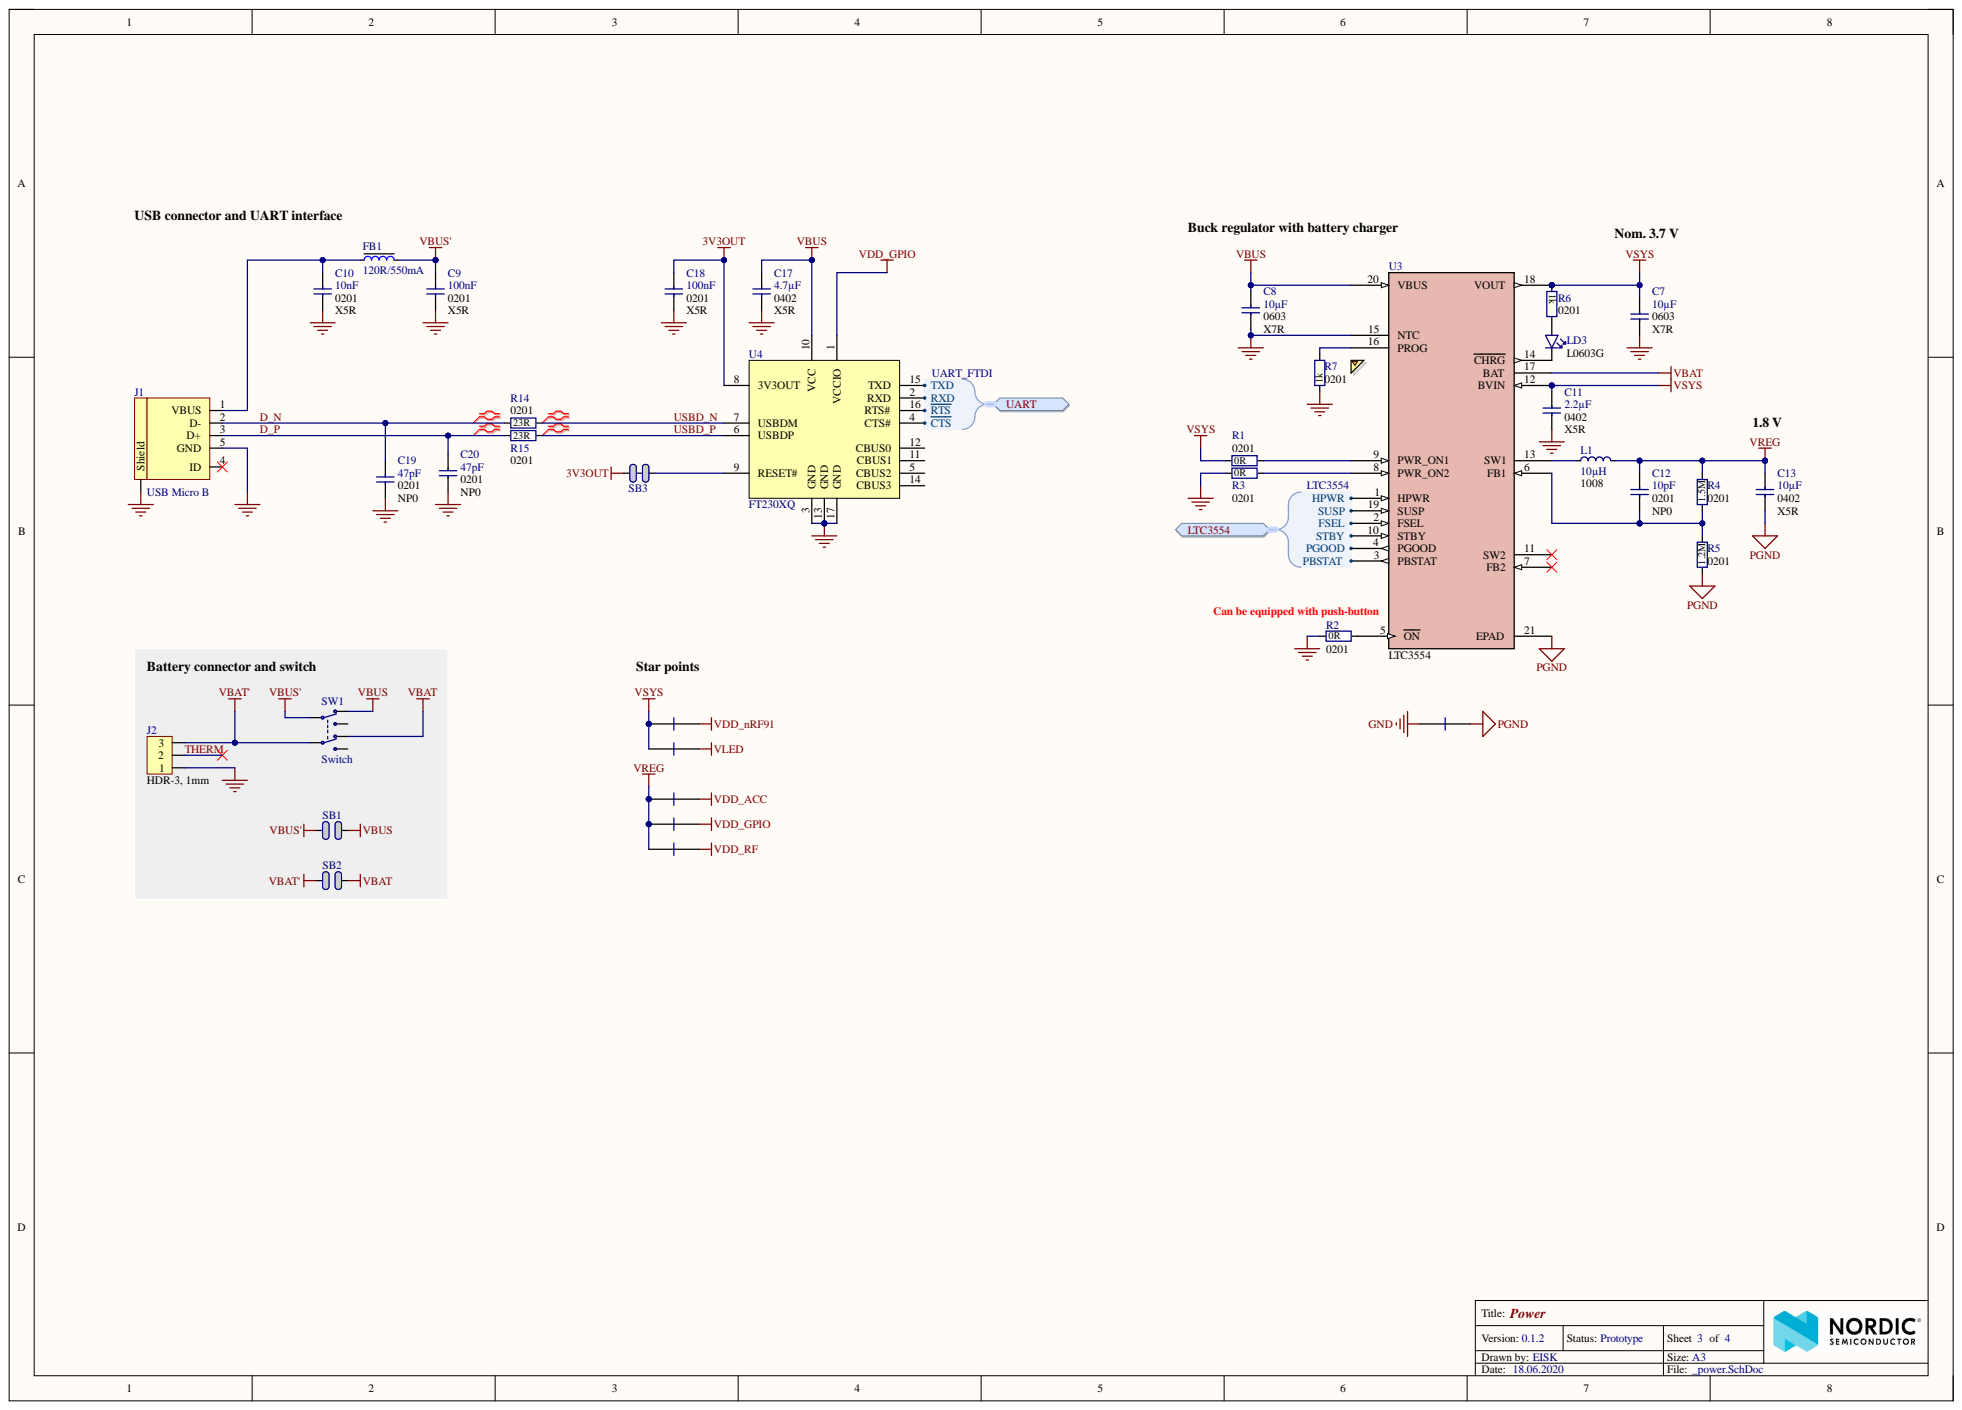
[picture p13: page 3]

uck regulator with battery charger

23R | USBD_P 6

Can be equipped with pu

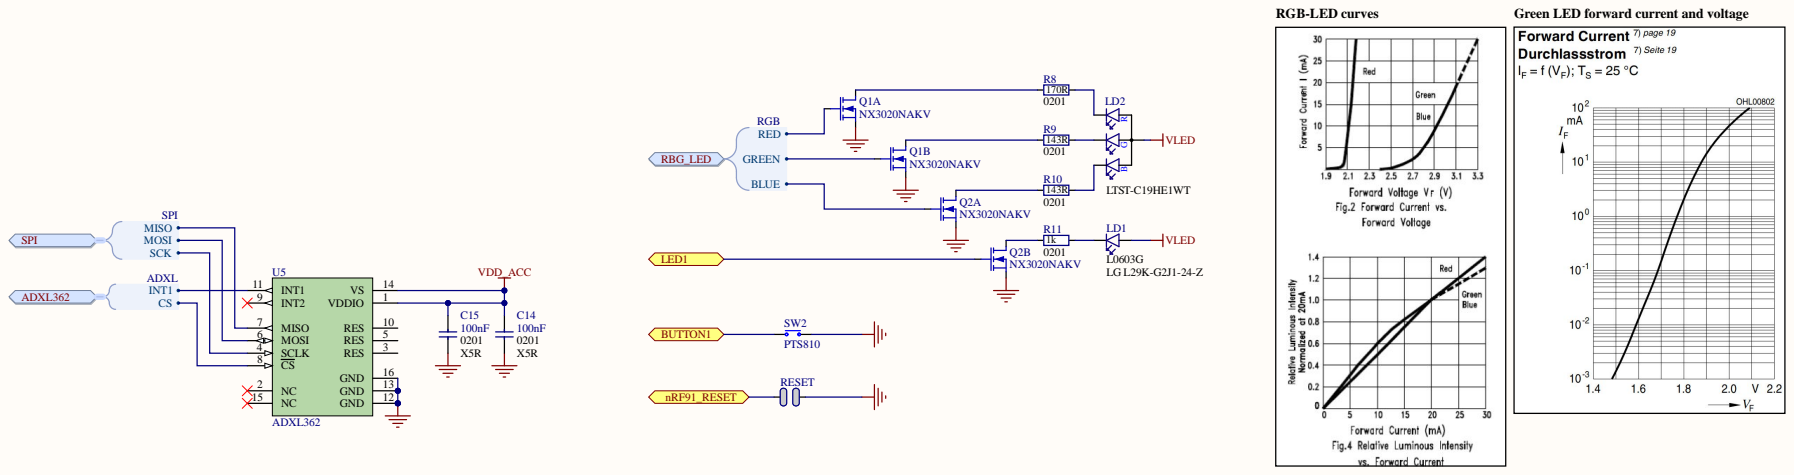
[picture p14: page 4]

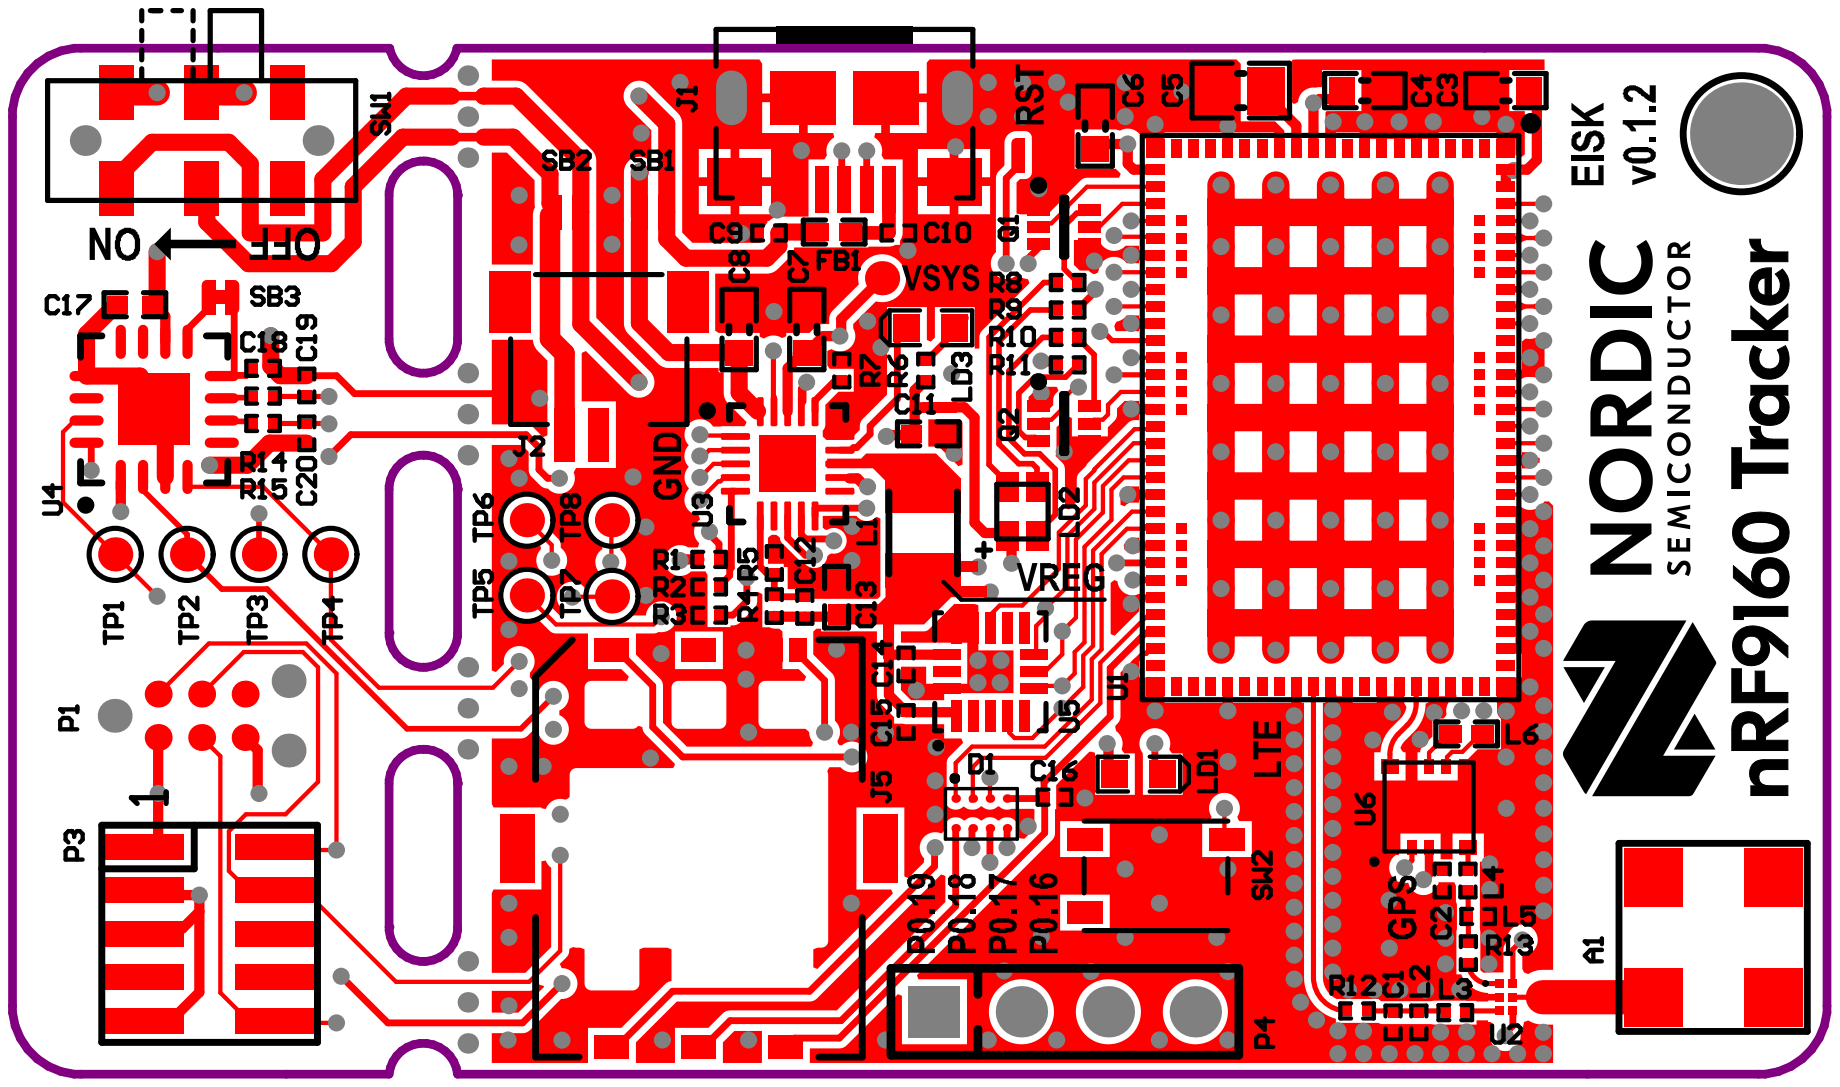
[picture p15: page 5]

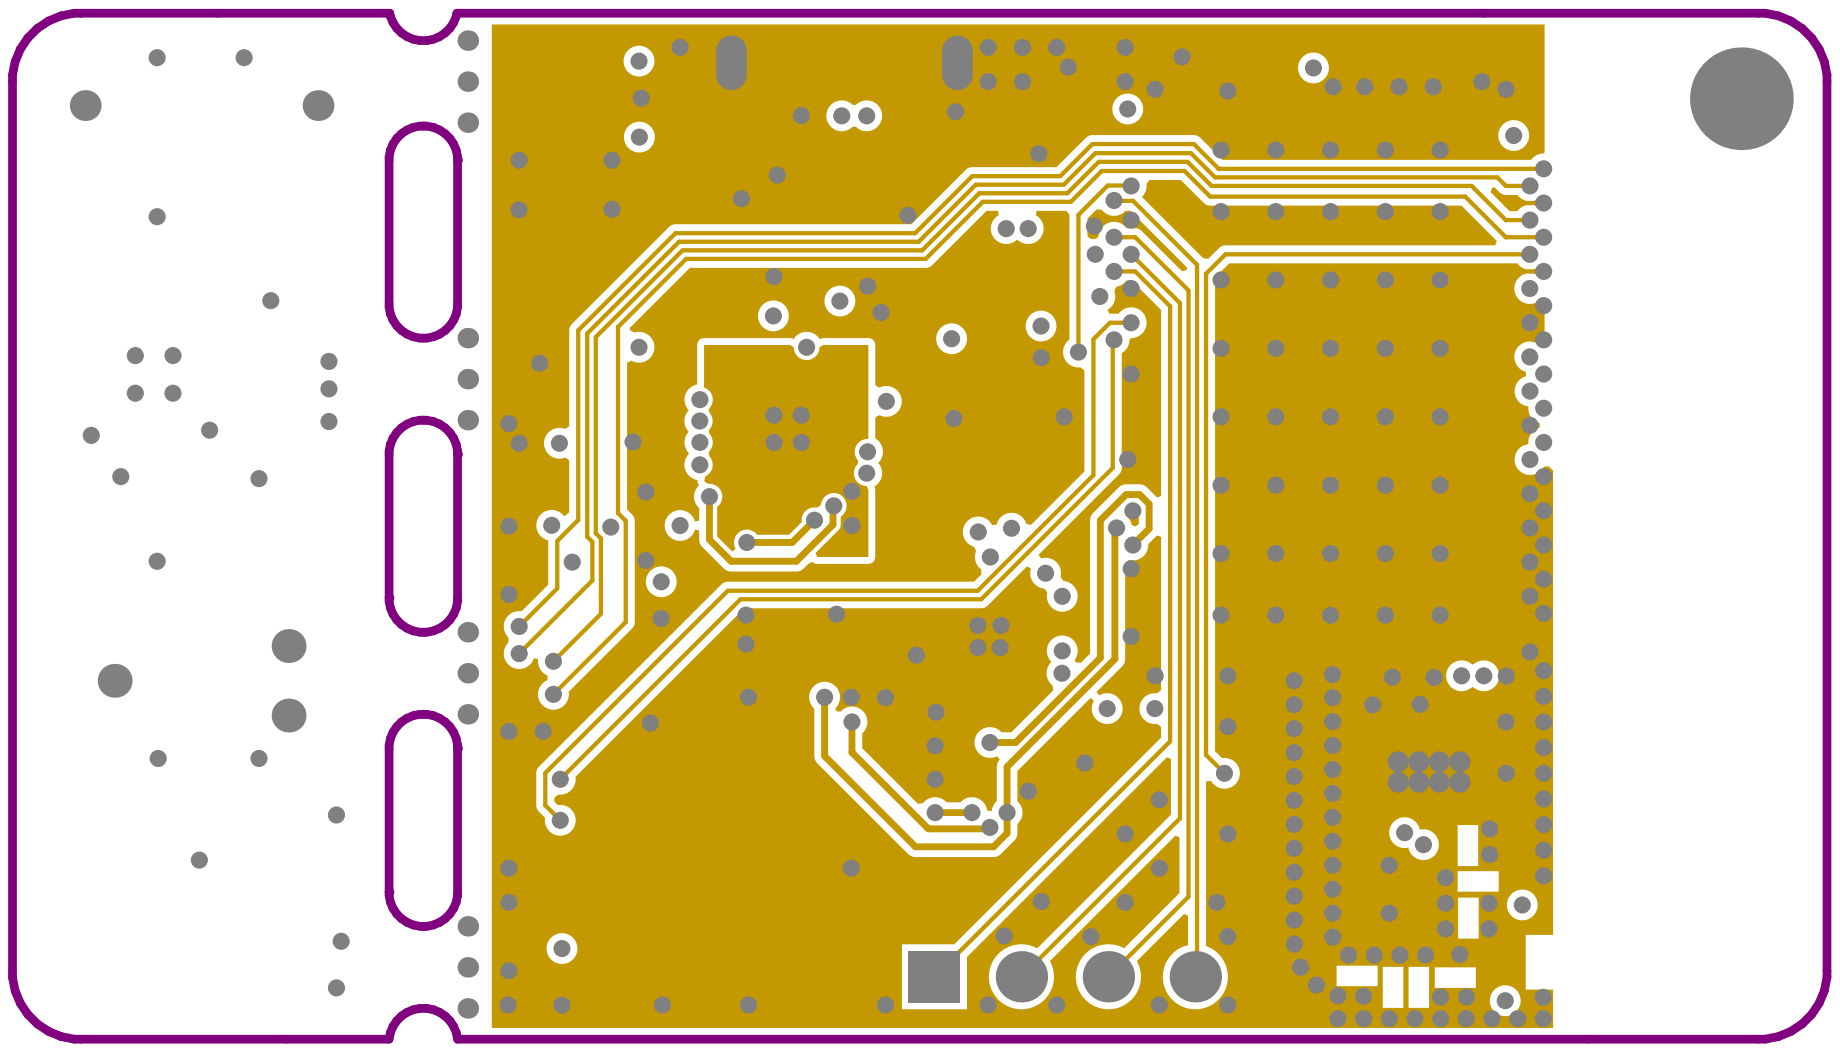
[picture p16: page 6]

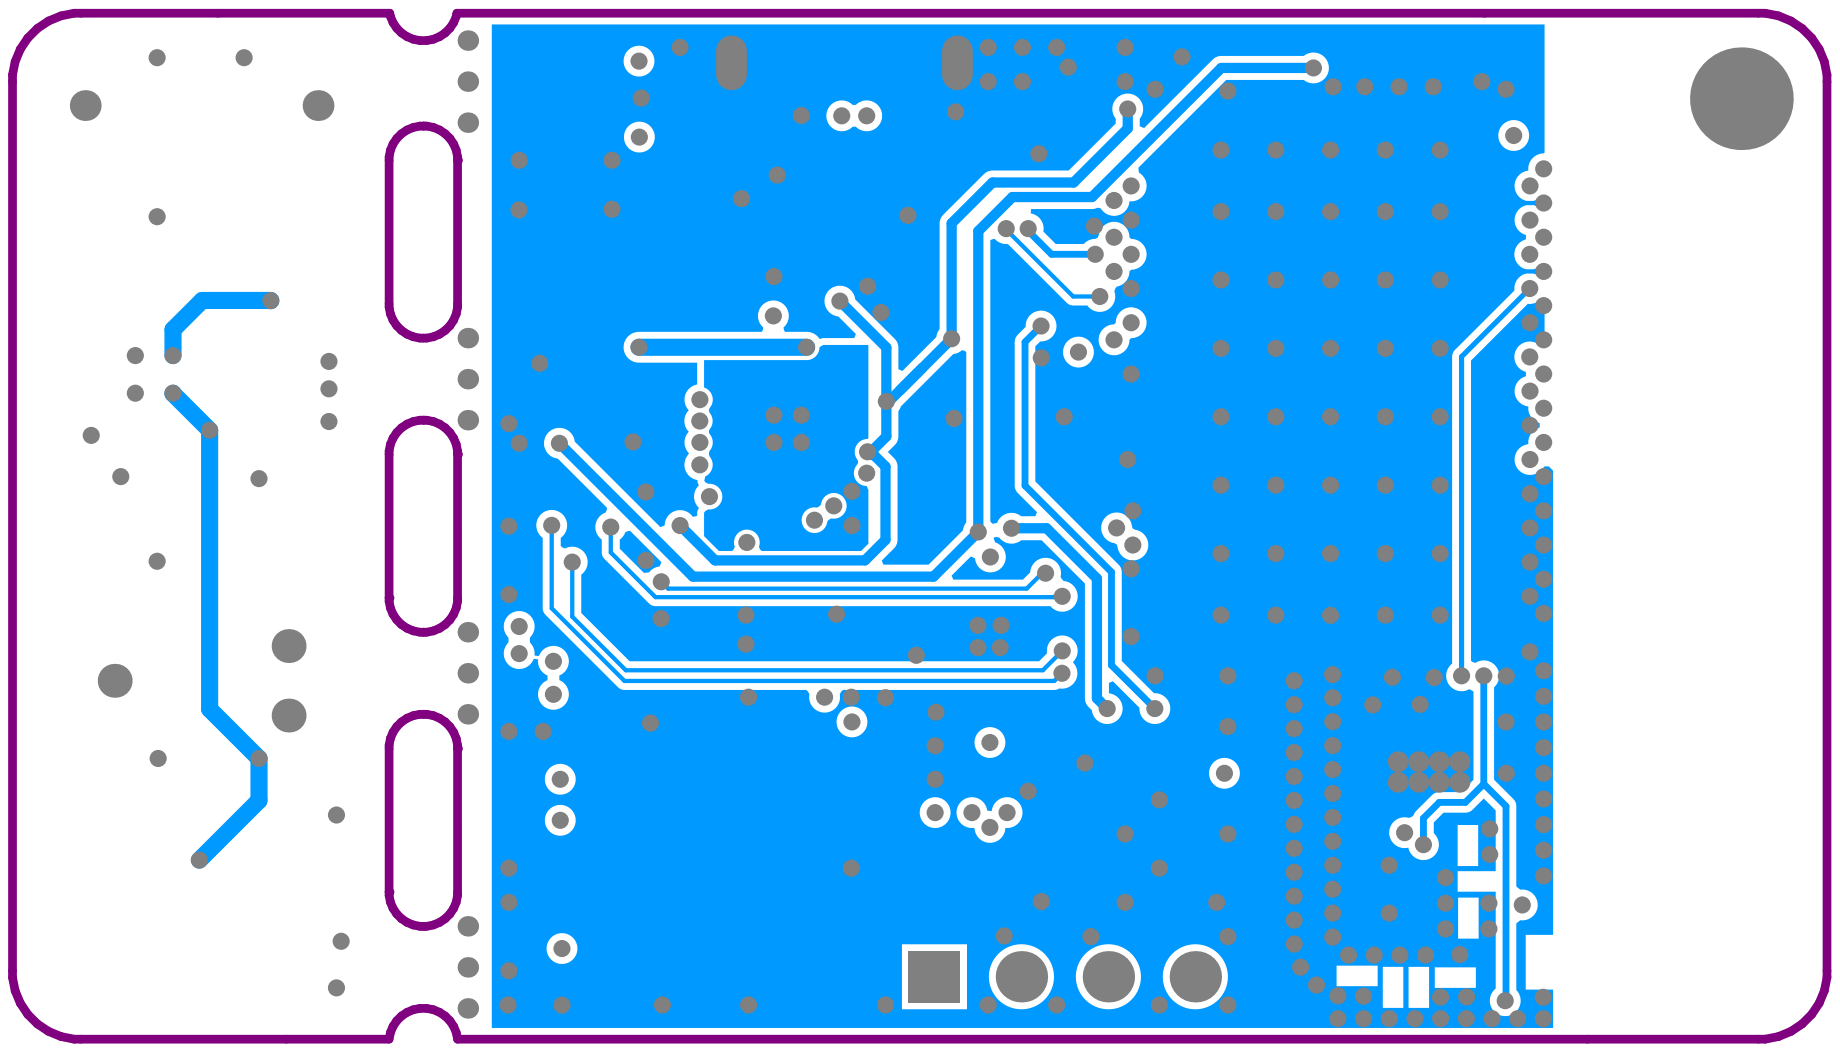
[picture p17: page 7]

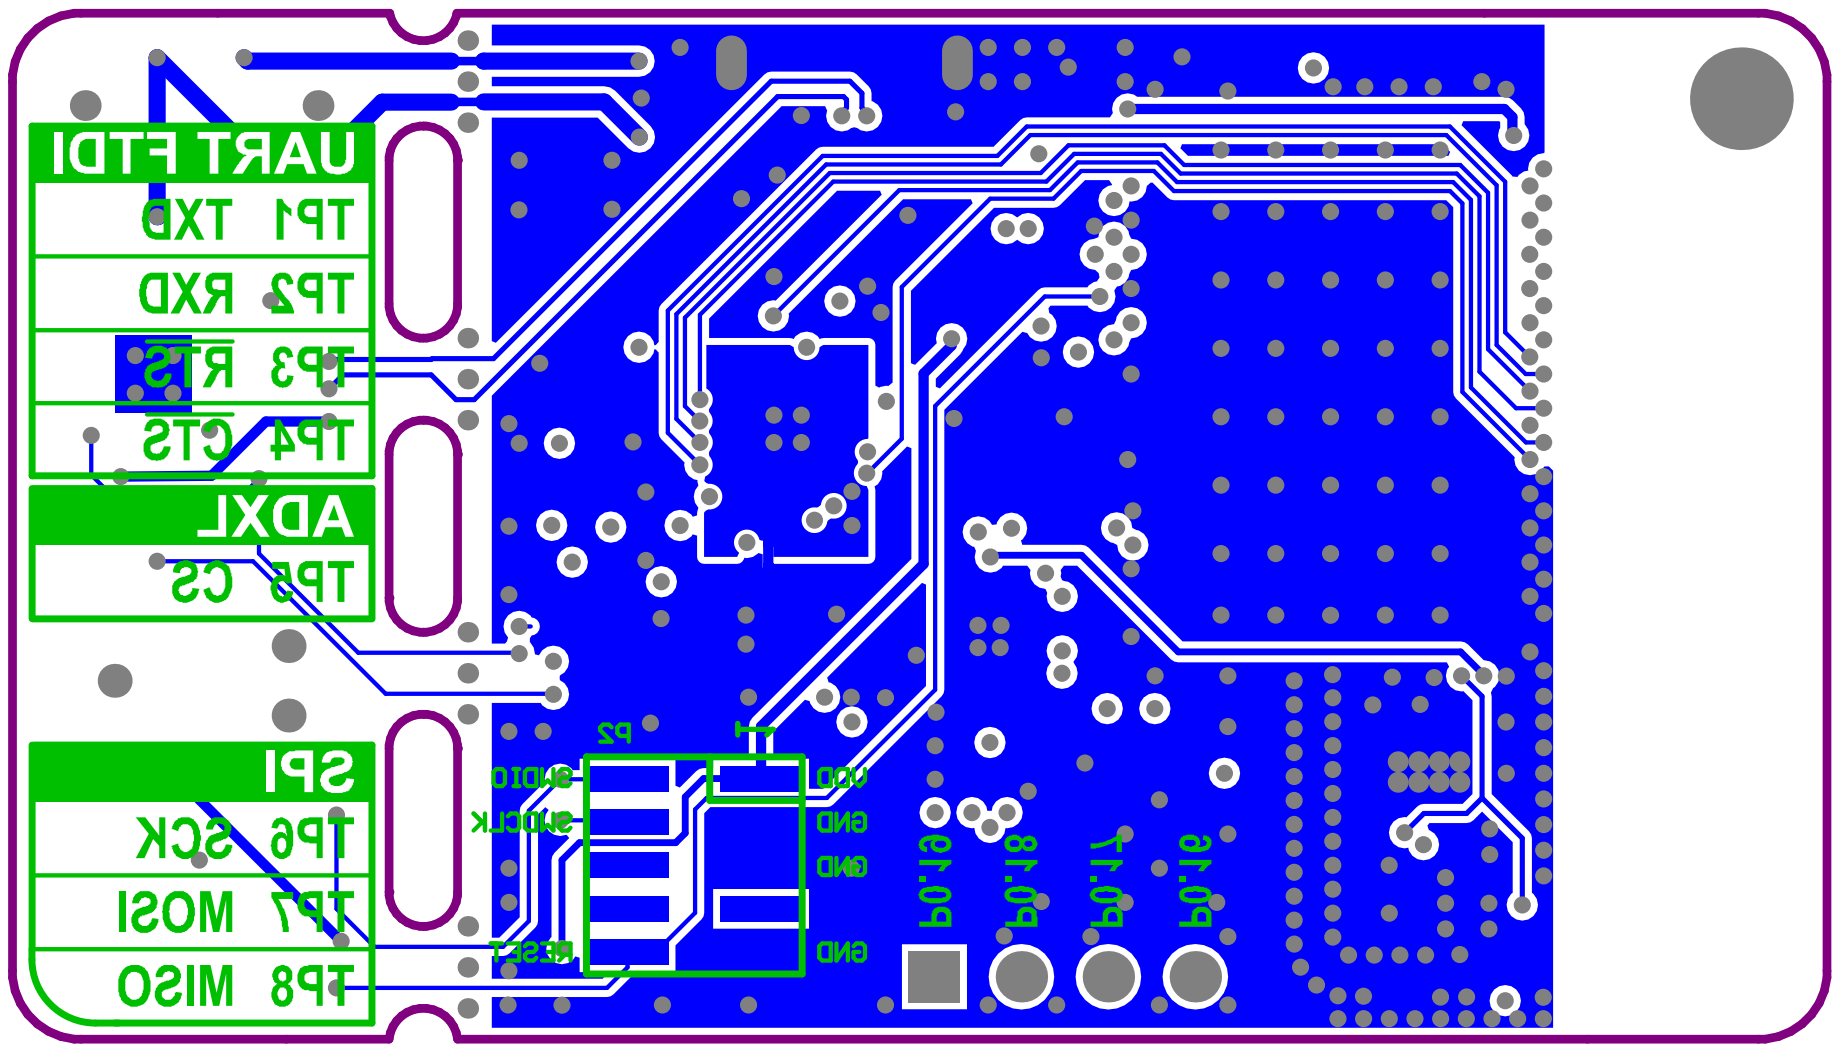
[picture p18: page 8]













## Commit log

2020-02-13 Add design files for version v0.1.1
    Fixes #1
    [BOM.xlsx, _components.SchLib, _main.SchDoc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]
2020-06-18 Version 0.1.2
    - VSYS on PWR_ON1 and COEX0 on RF frontend.
    - RF switch is flipped back to correct position.
    - minor visual corrections in the schematics.
    [_main.SchDoc, _nRF9160.SchDoc, _nRF9160_tracker.PrjPcb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]
